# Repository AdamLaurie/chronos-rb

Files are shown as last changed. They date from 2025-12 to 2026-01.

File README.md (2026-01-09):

# ⚛️ CHRONOS-Rb

**C**ompact **H**igh-precision **R**ubidium **O**scillator **N**etwork **O**perating **S**ystem

A Stratum-1 NTP/PTP time server for Raspberry Pi Pico 2-W, disciplined by an FE-5680A rubidium atomic frequency standard.





## 🎯 Features

- **Stratum-1 NTP Server** - Direct atomic reference, no upstream servers needed
- **IEEE 1588 PTP Support** - Sub-microsecond precision time protocol
- **Rubidium Disciplined** - 10⁻¹¹ frequency stability from FE-5680A
- **WiFi Connected** - Serves time over 802.11 b/g/n
- **Web Interface** - Real-time status and configuration
- **JSON API** - Integration with monitoring systems
- **OTA Updates** - Encrypted firmware updates over WiFi with automatic rollback
- **PIO Precision** - Hardware-timed capture for <1µs accuracy
- **Automatic Holdover** - Maintains accuracy during reference loss
- **Interval Pulse Outputs** - 0.5s, 1s, 6s, 30s, 60s timing signals
- **AC Mains Frequency Monitor** - Grid frequency tracking with 48-hour history

## 📊 Specifications

| Parameter | Value |
|---|---|
| NTP Stratum | 1 (when locked) |
| Time Accuracy | < 1 µs to UTC |
| Frequency Stability | < 5×10⁻¹¹ (1 day) |
| PPS Jitter | < 100 ns |
| Warmup Time | 3-5 minutes |
| Power Consumption | ~35W during warmup, ~12W running |

## 🔧 Hardware Requirements

### Main Components

1. **Raspberry Pi Pico 2-W** - RP2350 with WiFi
2. **FE-5680A Rubidium Oscillator** - 10MHz output (DB-9 version)
3. **GPS Module** - u-blox NEO-6M or similar with 1PPS output (~$10-15)
4. **15V 3A Power Supply** - For rubidium physics package
5. **LT1016 or MAX999 Comparator** - 10MHz sine-to-square conversion
6. **Signal Conditioning Components** - See BOM in documentation

### Block Diagram

```
┌─────────────────┐     ┌──────────────────┐     ┌─────────────────┐
│   FE-5680A      │     │ Signal           │     │ Raspberry Pi    │
│   Rubidium      │────▶│ Conditioning     │────▶│ Pico 2-W        │
│   Oscillator    │     │ Circuit          │     │                 │
└─────────────────┘     └──────────────────┘     └────────┬────────┘
       │                        ▲                         │
       │ 10MHz Sine             │ 1PPS + NMEA             │ WiFi
       │ Lock Status            │                         ▼
       │                 ┌──────┴───────┐         ┌───────────────┐
       │                 │  GPS Module  │         │ NTP/PTP       │
       │                 │  (NEO-6M)    │         │ Clients       │
       │                 └──────────────┘         └───────────────┘
       │
       └─ Rb provides frequency stability (10⁻¹¹)
          GPS provides UTC alignment (±10ns)
```

## 📁 Project Structure

```
chronos-rb/
├── firmware/
│   ├── CMakeLists.txt          # Build configuration
│   ├── flash.sh                # Flashing helper script
│   ├── ota_key.txt             # AES encryption key (gitignored)
│   ├── deps/
│   │   └── pico_fota_bootloader/  # A/B partition bootloader
│   ├── include/
│   │   ├── chronos_rb.h        # Main header with configs
│   │   └── ota_update.h        # OTA update API
│   └── src/
│       ├── main.c              # Entry point
│       ├── pps_capture.c       # 1PPS timing capture
│       ├── pps_capture.pio     # PIO program for PPS
│       ├── freq_counter.c      # 10MHz measurement
│       ├── freq_counter.pio    # PIO program for freq
│       ├── rubidium_sync.c     # Rb sync state machine
│       ├── time_discipline.c   # PI controller
│       ├── ntp_server.c        # NTPv4 implementation
│       ├── ptp_server.c        # IEEE 1588 PTP
│       ├── wifi_manager.c      # WiFi handling
│       ├── web_interface.c     # HTTP status page + OTA
│       └── ota_update.c        # OTA firmware updates
├── hardware/
│   └── schematics/             # KiCad files (future)
└── docs/
    └── CHRONOS-Rb_Hardware_Guide.docx
```

## 🚀 Quick Start

### 1. Configure WiFi

Edit `firmware/include/chronos_rb.h`:

```c
#define WIFI_SSID_DEFAULT    "YourNetwork"
#define WIFI_PASS_DEFAULT    "YourPassword"
#define WIFI_COUNTRY         "US"
```

### 2. Build Firmware

```bash
cd firmware
mkdir build && cd build
cmake -DPICO_SDK_PATH=/path/to/pico-sdk ..
make -j4
```

**Build outputs:**
| File | Purpose |
|---|---|
| `pico_fota_bootloader.uf2` | A/B partition bootloader (flash first) |
| `chronos_rb.uf2` | Application firmware |
| `chronos_rb_fota_image_encrypted.bin` | Encrypted image for OTA updates |

### 3. Flash to Pico (First Time)

For new devices, flash the bootloader first, then the application:

**Option A: Using make targets**
```bash
# Flash bootloader, wait for reboot, then flash application
make flash-initial
```

**Option B: Manual BOOTSEL flashing**
```bash
# Step 1: Hold BOOTSEL, connect USB, copy bootloader
cp deps/pico_fota_bootloader/pico_fota_bootloader.uf2 /media/$USER/RP2350/

# Step 2: Hold BOOTSEL again, copy application
cp chronos_rb.uf2 /media/$USER/RP2350/
```

**Subsequent updates** can use OTA (see below) or:
```bash
make flash-app
```

### 4. Wire Hardware

See the Hardware Guide document for complete schematics. Key connections:

| Pico GPIO | Signal | Source |
|---|---|---|
| GP0 | GPS TX (UART0 TX) | To GPS module RX |
| GP1 | GPS RX (UART0 RX) | From GPS module TX |
| GP2 | 1PPS Input | From GPS module PPS |
| GP20 | 10MHz Input | FE-5680A via comparator |
| GP4/GP5 | I2C0 (optional) | For OLED display |
| GP6-9 | Status LEDs | With 330Ω resistors |
| GP22 | Lock Status | FE-5680A pin 3 via NPN level shifter |
| GP14 | 0.5s Pulse | Interval output |
| GP15 | 1s Pulse | Interval output |
| GP16 | 6s Pulse | Interval output |
| GP17 | 30s Pulse | Interval output |
| GP18 | 60s Pulse | Interval output |
| GP19 | AC Zero Cross | Zero crossing detector (optional) |

### 5. Power Up

1. Connect 15V to FE-5680A
2. Wait 3-5 minutes for rubidium lock
3. Green LED indicates sync achieved
4. Access web UI at `http://<ip-address>/`

## 📡 Using the Time Server

### NTP Client (Linux)

```bash
# Test connection
ntpdate -q 192.168.1.100

# Configure as time source
sudo nano /etc/systemd/timesyncd.conf
# Add: NTP=192.168.1.100
sudo systemctl restart systemd-timesyncd
```

### NTP Client (Windows)

```powershell
w32tm /config /manualpeerlist:192.168.1.100 /syncfromflags:manual /update
w32tm /resync
```

### Web Interface

Navigate to `http://<device-ip>/` for real-time status:

- Sync state (INIT → FREQ_CAL → COARSE → FINE → LOCKED)
- Time offset (nanoseconds)
- Frequency correction (ppb)
- NTP request count
- PTP sync statistics

### JSON API

```bash
curl http://192.168.1.100/api/status
```

```json
{
  "sync_state": 4,
  "rb_locked": true,
  "time_valid": true,
  "offset_ns": 127,
  "freq_offset_ppb": 0.023,
  "pps_count": 3847,
  "ntp_requests": 1542
}
```

## 📦 OTA Firmware Updates

CHRONOS-Rb supports encrypted over-the-air updates with automatic rollback protection.

### How It Works

- **A/B Partitioning**: Two firmware slots allow safe updates without bricking
- **AES-128 Encryption**: Firmware images are encrypted with a device-specific key
- **SHA-256 Validation**: Images are verified before applying
- **Automatic Rollback**: If the new firmware fails to boot 3 times, the previous version is restored
- **Boot Confirmation**: Firmware must run successfully for 60 seconds to be marked as good

### Web Interface Update

1. Navigate to `http://<device-ip>/ota`
2. Click "Choose File" and select `chronos_rb_fota_image_encrypted.bin`
3. Click "Upload Firmware" and wait for upload + validation
4. Click "Apply & Reboot" to install the update

### API Update

```bash
# Get OTA status
curl http://192.168.1.100/api/ota/status

# Upload firmware (chunked)
FILE="chronos_rb_fota_image_encrypted.bin"
SIZE=$(stat -c%s "$FILE")

# Begin upload
curl -X POST -H "X-OTA-Size: $SIZE" http://192.168.1.100/api/ota/begin

# Upload in chunks (1KB each)
split -b 1024 "$FILE" /tmp/chunk_
for chunk in /tmp/chunk_*; do
    curl -X POST --data-binary @"$chunk" \
         -H "Content-Type: application/octet-stream" \
         http://192.168.1.100/api/ota/chunk
done

# Finalize and validate
curl -X POST http://192.168.1.100/api/ota/finish

# Apply update (device will reboot)
curl -X POST http://192.168.1.100/api/ota/apply
```

### Encryption Key

The first build generates a random AES-128 key in `firmware/ota_key.txt`. This file is gitignored to keep it secret.

**Important:**
- Keep `ota_key.txt` backed up - you need it to create valid update images
- All firmware builds must use the same key to be accepted by the device
- If you lose the key, you must reflash via BOOTSEL

### Recovery

If an update fails and automatic rollback doesn't work:

1. Hold BOOTSEL button while connecting USB
2. Copy `pico_fota_bootloader.uf2` to the drive
3. Wait for reboot, hold BOOTSEL again
4. Copy `chronos_rb.uf2` to the drive

## 🔬 How It Works

### Time Discipline Loop

```
    ┌─────────────────────────────────────────────────┐
    │                                                 │
    ▼                                                 │
┌───────┐    ┌──────────┐    ┌────────────┐    ┌─────┴─────┐
│ 1PPS  │───▶│ Capture  │───▶│ Calculate  │───▶│    PI     │
│ Input │    │ (PIO)    │    │  Offset    │    │ Controller│
└───────┘    └──────────┘    └────────────┘    └───────────┘
                                                     │
                                                     ▼
┌───────────┐    ┌──────────┐    ┌────────────┐    ┌─────────┐
│ Timestamp │◀───│ Apply    │◀───│ Frequency  │◀───│Correction│
│ Output    │    │ Correction│   │  Adjust    │    │  (ppb)  │
└───────────┘    └──────────┘    └────────────┘    └─────────┘
```

### Sync State Machine

```
INIT ──▶ FREQ_CAL ──▶ COARSE ──▶ FINE ──▶ LOCKED
  │          │           │          │         │
  └──────────┴───────────┴──────────┴─────────┘
                         │
                    (on error)
                         ▼
                     HOLDOVER ──▶ ERROR
```

## 📐 Signal Conditioning

### 10MHz Sine to Square Converter

The FE-5680A outputs a ~860mVpp sine wave at ~0.7V DC. An LT1016 high-speed comparator converts this to 3.3V LVCMOS for the Pico:

```
           +5V         +5V
            │           │
           R2          ┌┴┐
          (6.8k)       │C1│ 0.1µF
            │          └┬┘
FE-5680A    │           │
Pin 7 ─────R1────┬─────Pin 1 (V+)
(10MHz)   (100Ω) │
                 │    ┌────────────┐
            Pin 2├────┤            ├─Pin 8──R6───LED──GND
            (+IN)│    │   LT1016   │       (500Ω) (purple)
                 │    │            │
            Pin 3├────┤            ├─Pin 7──R4───┬───► GP20
            (-IN)│    └────────────┘       (100Ω)│    (~3V)
                 │     │   │   │              R5
                R3    Pin4 Pin5 Pin6         (220Ω)
               (1k)    │   │   │              │
                │      └───┴───┴──────────────┴───GND
               GND

Threshold: ~0.64V from R2/R3 divider
Level shift: 5V→3V via R4/R5 divider
LED: On Q̅ (pin 8), lights when output LOW (inverted indicator)
```

**Components:**
- R1: 100Ω (input series resistor)
- R2: 6.8kΩ (threshold divider, top)
- R3: 1kΩ (threshold divider, bottom) → ~0.64V at -IN
- R4: 100Ω (level shifter, top)
- R5: 220Ω (level shifter, bottom) → ~3V output
- R6: 500Ω (LED current limit)
- C1: 0.1µF (bypass capacitor)
- U1: LT1016 (5V supply, 10ns comparator)
- 1× Purple LED (10MHz signal indicator, inverted)

**Notes:**
- No hysteresis feedback needed for 860mVpp signal
- LED on Q̅ (pin 8) to reduce loading on Q (pin 7)
- Lower value level shifter resistors prevent RC filtering at 10MHz

### GPS Module (Required)

A GPS module provides two critical functions:
1. **1PPS signal** - UTC-aligned pulse marking exact second boundaries (±10ns)
2. **Time-of-day** - NMEA sentences with current UTC time via UART

The firmware counts 10MHz cycles from the rubidium oscillator and verifies against GPS 1PPS to ensure exactly 10,000,000 cycles per second. This provides rubidium-level frequency stability with GPS-level UTC alignment.

#### Recommended Module: u-blox NEO-6M

Widely available as breakout boards (GY-GPS6MV2, GY-NEO6MV2):
- **Price:** ~$10-15
- **1PPS accuracy:** ±10ns to UTC
- **Interface:** UART (9600 baud default) + 1PPS output
- **Voltage:** 3.3-5V (check your specific board)

**Alternative:** BN-220 (~$15-20) - smaller form factor, same chipset

#### Wiring

```
GPS Module                              Pico
───────────                             ────
VCC ────────────────────────────────── 3.3V (or 5V if module requires)
GND ────────────────────────────────── GND
TX  ────────────────────────────────── GP1 (UART0 RX)
RX  ────────────────────────────────── GP0 (UART0 TX)
PPS ────────────────────────────────── GP2 (1PPS input)
```

**Note:** Most 3.3V GPS modules can connect directly. For 5V modules, add level shifting on PPS:

```
GPS 1PPS ──── R4 ────┬──── To Pico GP2
(5V)        (2.2k)   │
                     R5
                    (3.3k)
                     │
                    GND

Divider: 5V × 3.3k/(2.2k+3.3k) ≈ 3.0V
```

### Lock Status Level Shifter

The FE-5680A lock output (Pin 3) is 4.8V when unlocked, 0.8V when locked. An NPN transistor inverts and level-shifts this to 3.3V logic:

```
                      +3.3V
                        │
FE-5680A               R8 (1k)              +3.3V
Pin 3 ─── R6 ───┬───── B     C ─────┬─────── GP22 (HIGH = locked)
(Lock)   (22k)  │      ┌─────┐      │
                │      │2N3904│      ├─ R9 ─── GREEN LED ─── GND
           R7 ──┴─ GND │  Q1  │      │  (330Ω)   (locked)
          (10k)        └──┬──┘       │
                          E          └─ R10 ── YELLOW LED ── +3.3V
                          │             (330Ω)  (unlocked)
                         GND

Operation:
- Unlocked (4.8V): Q1 ON  → collector LOW  → YELLOW on,  GREEN off
- Locked (0.8V):   Q1 OFF → collector HIGH → YELLOW off, GREEN on
```

**Components:**
- 1× 2N3904 NPN transistor
- R6: 22kΩ (base input)
- R7: 10kΩ (base to GND)
- R8: 1kΩ (collector pull-up to 3.3V)
- R9: 330Ω (green LED current limit)
- R10: 330Ω (yellow LED current limit)
- 1× Green LED (indicates locked)
- 1× Yellow LED (indicates unlocked/warmup)

### AC Mains Frequency Monitor (Optional)

CHRONOS-Rb can monitor local AC grid frequency using off-the-shelf components. Grid frequency is tightly regulated and varies with load, providing an interesting indicator of grid stability.

#### Components

1. **AC Transformer**: [Carel TRA12UN100](https://cpc.farnell.com/carel/tra12un100/transformer-240vac-12vac/dp/MC01881)
   - 240VAC to 12VAC isolation transformer
   - 3VA rating (300mA max)
   - **Important**: Safe for very low load designs - output voltage stays at 13.8V (no load) to 10V (full load), unlike doorbell transformers that can spike to dangerous voltages under light load

2. **Zero Crossing Detector**: [Lectrobox AC Zero Crossing Detector](https://www.lectrobox.com/projects/zero-crossing-detector/)
   - 12VAC input via 5.5mm barrel jack
   - 3.3V output (0V/3.3V square wave indicating AC polarity)
   - SMA output connector
   - Built-in 100Hz RC filter for glitch resistance
   - Originally designed for grid frequency/phase measurement

#### Wiring

```
AC Mains ──► Transformer ──► Zero Crossing ──► Pico
  240V        TRA12UN100      Detector         GP19
               12VAC        (5.5mm jack)     (via SMA)
```

| Connection | Signal |
|---|---|
| Transformer primary | 240VAC mains (with appropriate fusing/isolation) |
| Transformer secondary | 12VAC to zero crossing detector barrel jack |
| Zero crossing SMA | 3.3V square wave to GP19 |

#### Features

- **Real-time frequency display**: Current grid frequency with 3 decimal precision
- **Hierarchical averaging**: Second → minute → hour averaging for noise reduction
- **48-hour history**: Stores 60 minute samples + 48 hour samples (~432 bytes)
- **Graph page**: Visual display at `/acfreq` showing minute and hour trends
- **API endpoint**: `/api/ac_history` returns JSON with `minutes[]` and `hours[]` arrays

#### Safety Notes

⚠️ **CAUTION**: AC mains voltage is dangerous. The transformer provides galvanic isolation between mains and low-voltage circuits.

- Use appropriate fusing on the primary side
- Ensure transformer is rated for your local mains voltage (230/240V or 110/120V)
- The TRA12UN100 is specifically designed for low-power monitoring applications
- Never connect the Pico directly to mains voltage

## ⏱️ Interval Pulse Outputs

CHRONOS-Rb provides five precision timing outputs synchronized to the rubidium 1PPS reference:

| GPIO | Interval | Use Case |
|---|---|---|
| GP14 | 0.5 second | High-rate timing, servo synchronization |
| GP15 | 1 second | PPS distribution, general timing |
| GP16 | 6 second | GPS-compatible timing intervals |
| GP17 | 30 second | Calibration triggers |
| GP18 | 60 second | Minute markers, event logging |

**Specifications:**
- Output level: 3.3V LVCMOS (active high)
- Pulse width: 10ms
- Timing accuracy: Phase-locked to atomic 1PPS reference
- Drive capability: 12mA (use buffer IC for cables/higher loads)

## 🐛 Troubleshooting

| Issue | Cause | Solution |
|---|---|---|
| No lock after 10 min | Power issue | Check +15V supply (needs 2A) |
| Erratic 1PPS | Bad connection | Check signal conditioning |
| WiFi fails | Wrong region | Set correct WIFI_COUNTRY |
| High offset | Comparator issue | Verify 10MHz square wave |
| NTP timeout | Firewall | Open UDP port 123 |

## 📜 License

MIT License - See LICENSE file for details.

## 🙏 Acknowledgments

- Raspberry Pi Foundation for the Pico SDK
- The time-nuts community for rubidium oscillator knowledge
- NTP and PTP specification authors

---

**CHRONOS-Rb** - *Because every nanosecond counts* ⚛️⏱️

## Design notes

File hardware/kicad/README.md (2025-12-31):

# CHRONOS-Rb KiCad Project

This directory contains the KiCad hardware design files for the CHRONOS-Rb Rubidium Time Server signal conditioning and interface board.

## Requirements

- **KiCad Version:** 7.0 or later (8.0 recommended)
- **Target Platform:** Raspberry Pi Pico 2-W (RP2350 with WiFi)
- **Reference Clock:** FE-5680A Rubidium Frequency Standard

## Project Structure

```
kicad/
├── chronos_rb.kicad_pro     # Main project file
├── chronos_rb.kicad_sch     # Top-level schematic (block diagram)
├── power_supply.kicad_sch   # Power supply: 15V/5V/3.3V rails
├── signal_conditioning.kicad_sch  # 10MHz comparator & 1PPS level shifter
├── pico_interface.kicad_sch # Raspberry Pi Pico 2-W connections
├── connectors.kicad_sch     # FE-5680A & external connectors
├── sym-lib-table            # Symbol library references
├── fp-lib-table             # Footprint library references
├── symbols/
│   └── chronos_rb.kicad_sym # Custom symbol library
├── footprints/
│   └── chronos_rb.pretty/   # Custom footprint library
├── 3dmodels/                # 3D models for components
└── gerbers/                 # Manufacturing output files
```

## Design Rules (JLCPCB Compatible)

The project is configured with design rules suitable for JLCPCB manufacturing:

| Parameter | Value |
|---|---|
| Minimum trace width | 6 mil (0.1524 mm) |
| Minimum trace spacing | 6 mil (0.1524 mm) |
| Minimum via diameter | 0.5 mm |
| Minimum via drill | 0.3 mm |
| Minimum hole size | 0.3 mm |
| Copper to edge clearance | 0.3 mm |

## Schematic Hierarchy

1. **Top Level** (`chronos_rb.kicad_sch`)
   - Block diagram overview
   - Power distribution reference
   - Signal flow documentation

2. **Power Supply** (`power_supply.kicad_sch`)
   - 15V input for FE-5680A (2-3A during warmup)
   - 5V regulated rail for logic
   - 3.3V LDO for Pico and signal conditioning

3. **Signal Conditioning** (`signal_conditioning.kicad_sch`)
   - 10MHz sine-to-square converter (LT1016/MAX999)
   - 1PPS 5V to 3.3V level shifter
   - Lock status input conditioning
   - ESD protection

4. **Pico Interface** (`pico_interface.kicad_sch`)
   - Pico 2-W module connections
   - Decoupling and power filtering
   - Status LED drivers
   - Interval output buffers
   - Debug/programming headers

5. **Connectors** (`connectors.kicad_sch`)
   - FE-5680A DB-9 interface
   - DC power input
   - Optional external timing outputs (BNC/SMA)

## Usage

1. Open `chronos_rb.kicad_pro` in KiCad 7.0+
2. The top-level schematic shows the system block diagram
3. Double-click hierarchical sheets to navigate to sub-schematics
4. Custom symbols are in the `chronos_rb` library
5. Export gerbers to the `gerbers/` directory for manufacturing

## Critical Signals

| Signal | Description | Level |
|---|---|---|
| PPS_IN | 1PPS from divider or external GPS | 3.3V (level shifted if needed) |
| CLK_10MHZ | 10MHz reference | 3.3V LVCMOS (from 1Vpp sine) |
| RB_LOCK | Rubidium lock status | Active low, 3.3V |

## GPIO Mapping (Pico 2-W)

| GPIO | Function |
|---|---|
| GP2 | PPS input (PIO capture) |
| GP3 | 10MHz input (frequency counter) |
| GP4 | Rubidium lock status |
| GP6-9 | Status LEDs |
| GP14-18 | Interval pulse outputs |

## License

Open Source Hardware - See main project LICENSE file.

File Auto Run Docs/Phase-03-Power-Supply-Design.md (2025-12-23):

# Phase 03: Power Supply Design

This phase creates the complete power supply subsystem for CHRONOS-Rb using **mains AC input** (100-240V AC, 50/60Hz). The FE-5680A rubidium oscillator requires 15V at 2-3A during warmup (dropping to ~1A steady-state), while the signal conditioning and Pico require regulated 5V and 3.3V rails. The power supply includes a zero-crossing detector circuit to monitor local AC mains frequency via a GPIO input.

**SAFETY WARNING**: This design involves mains AC voltage which can cause serious injury or death. All mains-connected circuitry must be properly isolated, fused, and enclosed. Follow all local electrical codes and regulations.

## Specifications

- **Input**: 100-240V AC, 50/60Hz (universal mains input)
- **Outputs**: +15V @ 3A (FE-5680A), +5V @ 1A (logic), +3.3V @ 500mA (digital), +3.3V @ 100mA (analog)
- **Isolation**: Reinforced isolation between mains and low-voltage sections
- **Features**: Mains frequency monitoring via GPIO (zero-crossing detector)

## Power Conversion Block Diagram

```
┌─────────────────────────────────────────────────────────────────────────────┐
│                              MAINS SIDE (HAZARDOUS)                         │
│  ┌─────────┐    ┌─────────┐    ┌─────────┐    ┌─────────┐    ┌──────────┐  │
│  │ IEC C14 │───>│  Fuse   │───>│   EMI   │───>│ Bridge  │───>│  Bulk    │  │
│  │  Inlet  │    │   2A    │    │ Filter  │    │Rectifier│    │  Cap     │  │
│  │100-240V │    │slow-blow│    │  + MOV  │    │ GBU806  │    │470uF/400V│  │
│  └─────────┘    └─────────┘    └─────────┘    └─────────┘    └────┬─────┘  │
│                                     │                              │        │
│                                     │                         140-340V DC   │
│                                     │                              │        │
│                              ┌──────┴──────┐               ┌───────┴──────┐ │
│                              │Zero-Crossing│               │   Isolated   │ │
│                              │  Detector   │               │   Flyback    │ │
│                              │   H11AA1    │               │  DC-DC Conv  │ │
│                              └──────┬──────┘               └───────┬──────┘ │
│                                     │                              │        │
├─────────────────────────────────────│──────────────ISOLATION───────│────────┤
│                              LOW VOLTAGE SIDE                      │        │
│                                     │                              │        │
│                              ┌──────┴──────┐               ┌───────┴──────┐ │
│                              │   GP19      │               │    +15V      │ │
│                              │  (Pico)     │               │   @ 3A       │ │
│                              │AC_ZERO_CROSS│               │  (FE-5680A)  │ │
│                              └─────────────┘               └───────┬──────┘ │
│                                                                    │        │
│                                                            ┌───────┴──────┐ │
│                                                            │   LM2596     │ │
│                                                            │  Buck Conv   │ │
│                                                            └───────┬──────┘ │
│                                                                    │        │
│                                                            ┌───────┴──────┐ │
│                                                            │     +5V      │ │
│                                                            │    @ 1A      │ │
│                                                            └───────┬──────┘ │
│                                                                    │        │
│                                                     ┌──────────────┼───────┐│
│                                                     │              │       ││
│                                              ┌──────┴─────┐ ┌──────┴─────┐ ││
│                                              │ AMS1117    │ │  LP5907    │ ││
│                                              │   LDO      │ │ Low-noise  │ ││
│                                              └──────┬─────┘ └──────┬─────┘ ││
│                                                     │              │       ││
│                                              ┌──────┴─────┐ ┌──────┴─────┐ ││
│                                              │+3.3V Digital│ │+3.3V Analog│ ││
│                                              │  @ 500mA   │ │  @ 100mA   │ ││
│                                              └────────────┘ └────────────┘ ││
└─────────────────────────────────────────────────────────────────────────────┘
```

## Zero-Crossing Detector Circuit

The H11AA1 is an AC-input optocoupler with two back-to-back LEDs, providing isolation while detecting both positive and negative zero crossings of the AC waveform.

```
        MAINS SIDE                    │            LOW VOLTAGE SIDE
        (ISOLATED)                    │
                                      │
    AC Live (L) ───┬──────────────────│
                   │                  │
                  ┌┴┐                 │
                  │ │ R1              │
                  │ │ 47k 1/2W        │
                  └┬┘                 │              +3.3V
                   │                  │                │
                  ┌┴┐                 │               ┌┴┐
                  │ │ R2              │               │ │ R3
                  │ │ 47k 1/2W        │               │ │ 10k
                  └┬┘                 │               └┬┘
                   │    ┌─────────┐   │                │
                   ├────┤1  H11AA1├───│────────────────┼──────> To GP19
                   │    │   opto  │   │                │        (AC_ZERO_CROSS)
                   │  ┌─┤2       4├─┬─│────────────────┘
                   │  │ └─────────┘ │ │
                   │  │             │ │
    AC Neutral (N)─┴──┴─────────────┴─│─────> GND (isolated from mains)
                                      │
                                      │
                              ISOLATION BARRIER
                              (3kV reinforced)
```

**Component Details:**
- **R1, R2**: 47kΩ 1/2W resistors in series (94kΩ total) - limits LED current to ~2.5mA at 240VAC peak
- **H11AA1**: AC-input optocoupler with back-to-back LEDs, 5.3kV isolation rating
- **R3**: 10kΩ pull-up to 3.3V - output is LOW during zero-crossing, HIGH otherwise

**Output Signal:**
- Produces a pulse at each zero crossing (both positive and negative)
- Pulse frequency = 2× mains frequency (100Hz for 50Hz mains, 120Hz for 60Hz mains)
- Firmware measures time between pulses to calculate mains frequency
- Connected to **GP19** (GPIO_AC_ZERO_CROSS) on Pico 2-W

## Tasks

### AC Input Section (Mains-Isolated)
- [ ] In `power_supply.kicad_sch`, create the AC mains input section with IEC C14 inlet connector (fused, with EMI filter)
- [ ] Add mains fuse holder with 2A slow-blow fuse (5x20mm) on the live conductor
- [ ] Add MOV (Metal Oxide Varistor) across L-N for transient surge suppression (275V AC rating, e.g., EPCOS B72210S0271K101)
- [ ] Add X2-class capacitor (100nF 275VAC) across L-N for differential mode EMI filtering
- [ ] Add Y1-class capacitors (2x 2.2nF 250VAC) from L and N to PE (protective earth) for common mode filtering
- [ ] Add common mode choke (10mH, 3A rated) for EMI suppression
- [ ] Create a clearly marked **HAZARDOUS VOLTAGE AREA** on schematic with safety notes

### Bridge Rectifier and Bulk Capacitor
- [ ] Add full-bridge rectifier (GBU806 or KBU810, 600V/8A rating) with proper heatsinking consideration
- [ ] Add bulk capacitor: 470uF/400V electrolytic for energy storage (calculate ripple current rating)
- [ ] Add bleeder resistor (470k, 1W) across bulk capacitor for discharge when unplugged
- [ ] Calculate DC bus voltage: ~140V DC (100V AC) to ~340V DC (240V AC)

### Isolated DC-DC Converter (15V Output)
- [ ] Use isolated flyback or forward converter topology for 15V @ 3A output (e.g., based on TNY290PG or similar offline switcher)
- [ ] Alternatively, use a pre-built AC-DC module (Mean Well IRM-45-15 or similar) for safety and certification
- [ ] Add opto-isolator (PC817 or 4N35) for feedback loop isolation
- [ ] Add isolation transformer with proper creepage/clearance distances (reinforced isolation, 3kV minimum)
- [ ] Add output capacitors: 1000uF/25V electrolytic + 100nF ceramic for the 15V rail
- [ ] Create the 15V filtered output for FE-5680A with additional LC filter: 10uH inductor, 100uF output capacitor

### Zero-Crossing Detector (Mains Frequency Monitor)
- [ ] Create isolated zero-crossing detector circuit using optocoupler (H11AA1 or similar AC-input opto)
- [ ] Add 100k current-limiting resistors (2x 47k in series for voltage rating) from mains L-N to opto LED
- [ ] Output: 3.3V-compatible pulse on each zero crossing (100/120 Hz for 50/60 Hz mains)
- [ ] Connect opto collector to GPIO with 10k pull-up to 3.3V
- [ ] Add net label: AC_ZERO_CROSS (connects to Pico GPIO for frequency measurement)
- [ ] Add schematic note: "Pulse output at 2x mains frequency for firmware frequency measurement"

### Secondary Regulators (5V and 3.3V Rails)
- [ ] Create the 5V switching regulator section from 15V input using LM2596-5.0 or TPS5430
- [ ] Add input capacitors (100uF/25V), output inductor (68uH), output capacitors (220uF + 100nF), Schottky diode (SS34)
- [ ] Add output voltage test point for the 5V rail with silk screen label "5V_TEST"
- [ ] Create the 3.3V LDO section using AMS1117-3.3 or AP2112K-3.3 from 5V input
- [ ] Add input capacitor (10uF), output capacitors (10uF + 100nF)
- [ ] Add a second 3.3V LDO specifically for analog circuits (comparator supply) using low-noise regulator LP5907-3.3
- [ ] Create power-on LED indicators: green LED with 1k resistor from 3.3V rail, amber LED with 2.2k resistor from 5V rail

### Protection and Monitoring
- [ ] Add current sense resistor (0.1 ohm, 1W) in the 15V path for monitoring warmup current
- [ ] Add power good output signal using voltage supervisor circuit (TL7705) monitoring 5V rail
- [ ] Add power rail decoupling network: 100uF bulk + 10uF + 100nF + 10nF for each rail
- [ ] Add TVS diode (SMBJ18A) on 15V output for secondary-side surge protection

### Documentation and Labels
- [ ] Create power sequencing note: "15V powers up first (from AC-DC), then 5V, then 3.3V (cascaded regulators)"
- [ ] Add net labels: +15V_RB, +5V, +3V3_DIGITAL, +3V3_ANALOG, GND, PWR_GOOD, AC_ZERO_CROSS
- [ ] Add power dissipation calculations as text notes
- [ ] Add safety markings: "DANGER: HIGH VOLTAGE", isolation boundary markers
- [ ] Add hierarchical labels for power outputs connecting to other sheets
- [ ] Document creepage/clearance requirements for mains isolation (minimum 6mm creepage for reinforced isolation)

### Firmware Integration
- [ ] Add GPIO_AC_ZERO_CROSS pin definition to chronos_rb.h (recommend GP19 or GP20)
- [ ] Create ac_freq_monitor.c/h module to measure mains frequency from zero-crossing pulses
- [ ] Add CLI command "acfreq" to display measured mains frequency
- [ ] Display AC frequency in status output and web interface

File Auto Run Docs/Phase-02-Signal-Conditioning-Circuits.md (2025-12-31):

# Phase 02: Signal Conditioning Circuits

This phase implements the critical signal conditioning circuits that convert the FE-5680A rubidium oscillator outputs into Pico-compatible logic levels. The 10MHz sine wave requires conversion to 3.3V LVCMOS using a high-speed comparator. Note: Most FE-5680A units (including the DB-9 version) do NOT have a native 1PPS output - it must be derived from the 10MHz using a divider circuit or sourced from an external GPS/GNSS receiver. If using an external 5V 1PPS source, level shifting with ESD protection is required.

## Tasks

- [ ] Create a custom KiCad symbol for the LT1016 high-speed comparator in `symbols/chronos_rb.kicad_sym` with all pins: +IN (pin 2), -IN (pin 3), V+ (pin 8), V- (pin 4), OUT (pin 7), GND (pin 1), LATCH (pin 5), Q_bar (pin 6)
- [ ] Create an alternative symbol for MAX999 comparator as a drop-in option with compatible pinout
- [ ] In `signal_conditioning.kicad_sch`, create the 10MHz comparator circuit section with LT1016, input AC coupling capacitor (100nF), bias resistor divider (10k/10k) to set DC operating point at V+/2
- [ ] Add 50-ohm input termination resistor for the 10MHz signal to match FE-5680A output impedance
- [ ] Add decoupling capacitors for the LT1016: 100nF ceramic on V+ to GND, 10uF tantalum on V+ to GND
- [ ] Add a hysteresis feedback network to the comparator (100k from output to +IN, optional 1M to threshold) to prevent oscillation on slow edges
- [ ] Add output series resistor (33 ohm) on comparator output to limit edge rate and reduce EMI
- [ ] Create the 1PPS level shifter section (for external 5V source) using resistive divider: 1.8k from 5V input, 3.3k to GND, achieving 3.08V output from 5V input
- [ ] Add BAT54S Schottky diode clamp from divider output to 3.3V rail and GND for overvoltage/ESD protection
- [ ] Add 100pF capacitor across the lower resistor of the divider to preserve fast PPS edges while filtering noise
- [ ] Create input protection on the 1PPS line: 100 ohm series resistor before the divider to limit surge current
- [ ] Add a buffer stage after the 1PPS divider using a 74LVC1G17 Schmitt trigger for clean digital edges (optional but recommended section)
- [ ] Create the RB_LOCK status input circuit: NPN transistor (2N3904) level shifter with 22k input resistor, 10k base-to-GND resistor, 10k collector pull-up to 3.3V. FE-5680A outputs 4.8V (unlocked) / 0.8V (locked), transistor inverts to GPIO HIGH=locked, LOW=unlocked
- [ ] Add net labels to all signal conditioning outputs: CLK_10MHZ_3V3, PPS_3V3, RB_LOCK_3V3
- [ ] Add test points (TP symbols) at critical nodes: 10MHz input, 10MHz output, 1PPS input (from divider/ext), 1PPS output, comparator threshold
- [ ] Create hierarchical labels for signals that connect to the Pico Interface sheet
- [ ] Add component annotations and values for all parts with designator prefixes: U for ICs, R for resistors, C for capacitors, D for diodes, TP for test points
- [ ] Add text notes on the schematic explaining signal levels: "Input: 1Vpp sine @ 10MHz" and "Output: 3.3V LVCMOS @ 10MHz, <1ns jitter"

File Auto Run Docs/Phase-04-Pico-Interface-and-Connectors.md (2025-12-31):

# Phase 04: Pico Interface and Connectors

This phase designs the Raspberry Pi Pico 2-W interface circuitry and all external connectors. The Pico serves as the main processor running the NTP/PTP server firmware, receiving timing signals from the signal conditioning stage. This phase also includes the FE-5680A connector interface, status LEDs, debug headers, and optional expansion connectors for external timing outputs.

## Tasks

- [ ] Create or import a Raspberry Pi Pico 2-W symbol in `symbols/chronos_rb.kicad_sym` showing all 40 pins with correct GPIO assignments per RP2350 datasheet
- [ ] In `pico_interface.kicad_sch`, place the Pico 2-W symbol with proper orientation (USB connector facing board edge)
- [ ] Create two 20-pin female header footprints for Pico mounting (2.54mm pitch, standard Pico socket arrangement)
- [ ] Connect power pins: VSYS to 5V rail, 3V3_EN to 3.3V (via 10k pullup), GND pins to ground plane
- [ ] Connect timing inputs from signal conditioning: GP2 to PPS_3V3, GP3 to CLK_10MHZ_3V3, GP4 to RB_LOCK_3V3
- [ ] Add 33 ohm series resistors on timing inputs for trace impedance matching and ESD protection
- [ ] Create status LED circuit section with 4 LEDs: green (GP6/SYNC), blue (GP7/NETWORK), yellow (GP8/ACTIVITY), red (GP9/ERROR)
- [ ] Add 470 ohm current limiting resistors for each LED (approximately 5mA per LED at 3.3V)
- [ ] Connect optional RB_ENABLE output on GP5 with 10k series resistor for FE-5680A control
- [ ] Create debug/diagnostic output section: GP10 (PPS_OUT), GP11 (SYNC_PULSE) with series resistors and test points
- [ ] Connect UART debug pins: GP0 (TX) and GP1 (RX) to a 3-pin debug header (TX, RX, GND)
- [ ] Create I2C header for optional OLED display: GP12 (SDA), GP13 (SCL), 3.3V, GND on a 4-pin connector
- [ ] Add I2C pull-up resistors (4.7k) on SDA and SCL lines
- [ ] Create interval pulse output section on GP14-GP18 with individual 100 ohm series resistors
- [ ] Add a 6-pin header for interval pulse outputs: 0.5s, 1s, 6s, 30s, 60s, and GND
- [ ] In `connectors.kicad_sch`, create the FE-5680A connector interface using a DB-9 female connector
- [ ] Map DB-9 pins per FE-5680A pinout: pin 1 (+15V), pin 2 (GND), pin 3 (LOCK), pin 4 (+5V), pin 5 (GND), pin 7 (10MHz)
- [ ] Note: 1PPS may need to be derived from 10MHz using a divider circuit (not all FE-5680A units have 1PPS output)
- [ ] Create a 2-pin screw terminal for +15V power input as alternative to barrel jack
- [ ] Add a USB-C or micro-USB breakout connector for Pico programming access
- [ ] Create an SMA or BNC connector footprint for external 10MHz reference output (active buffer from Pico output)
- [ ] Add an SMA connector for external 1PPS output with 50-ohm driver circuit using 74LVC2G17 buffer
- [ ] Create mounting hole symbols (M3) at board corners, connected to GND for shielding
- [ ] Add board edge connector for stacking or enclosure integration (2x10 pin header with power and key signals)
- [ ] Create net labels for all GPIO connections matching firmware definitions in chronos_rb.h
- [ ] Add hierarchical labels connecting all sheets together for power and signals

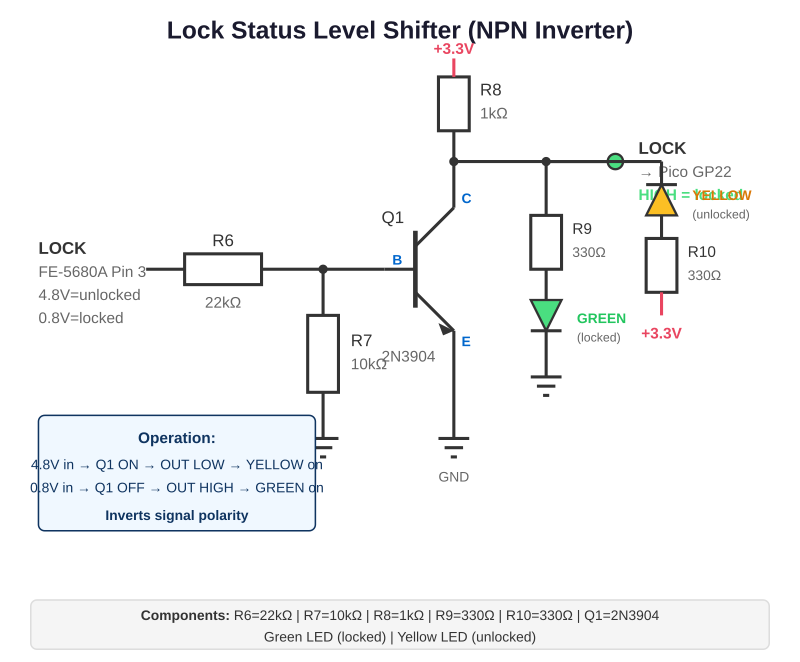
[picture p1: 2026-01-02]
hardware/lock_detector.png

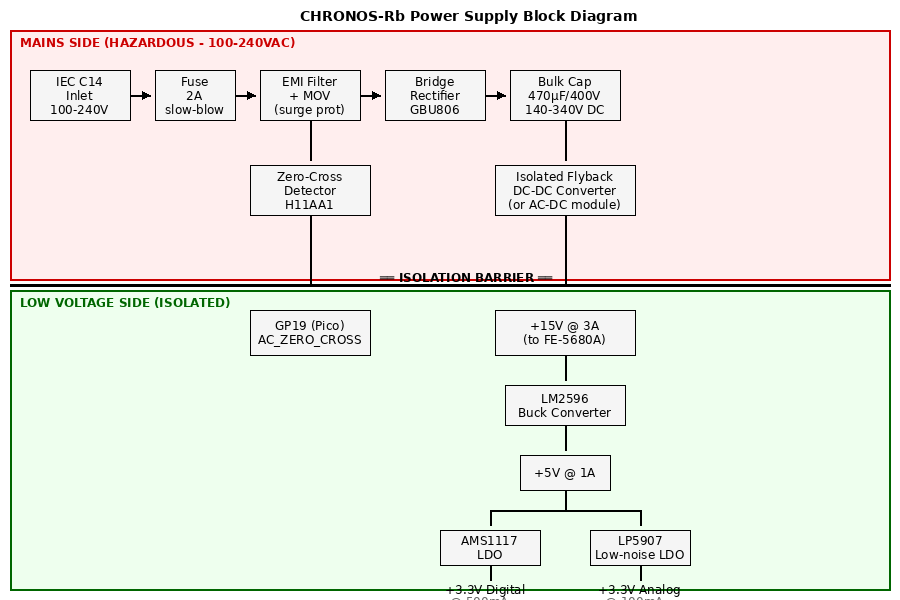
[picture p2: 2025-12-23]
hardware/power_supply.png

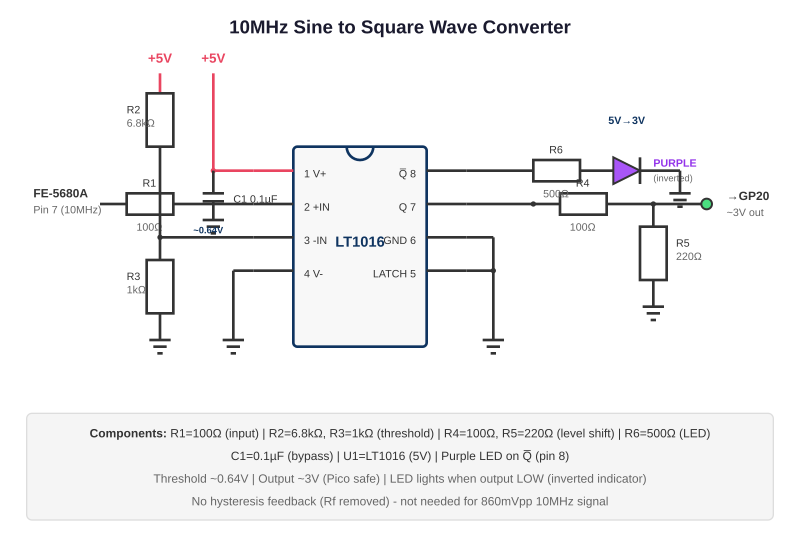
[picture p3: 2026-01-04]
hardware/10mhz_comparator.png

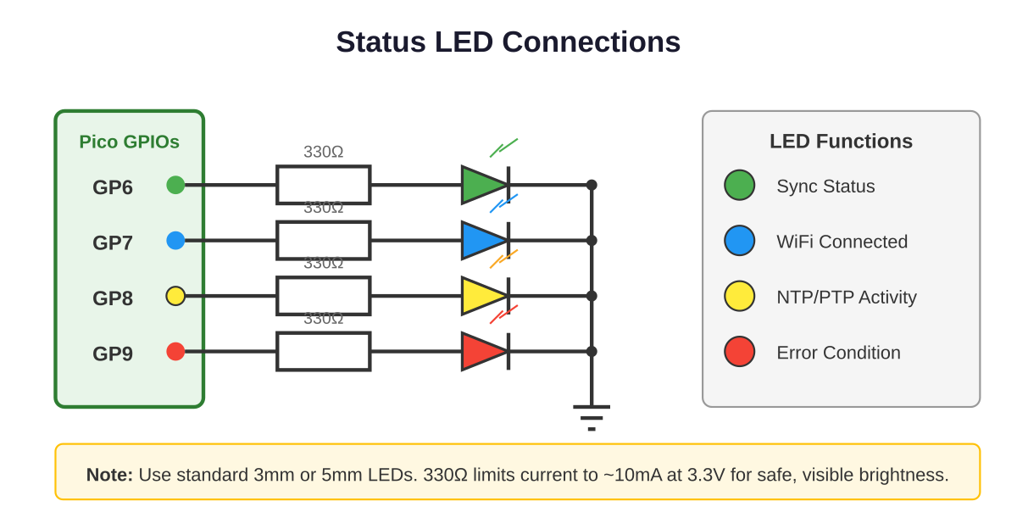
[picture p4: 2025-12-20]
hardware/led_circuit.png

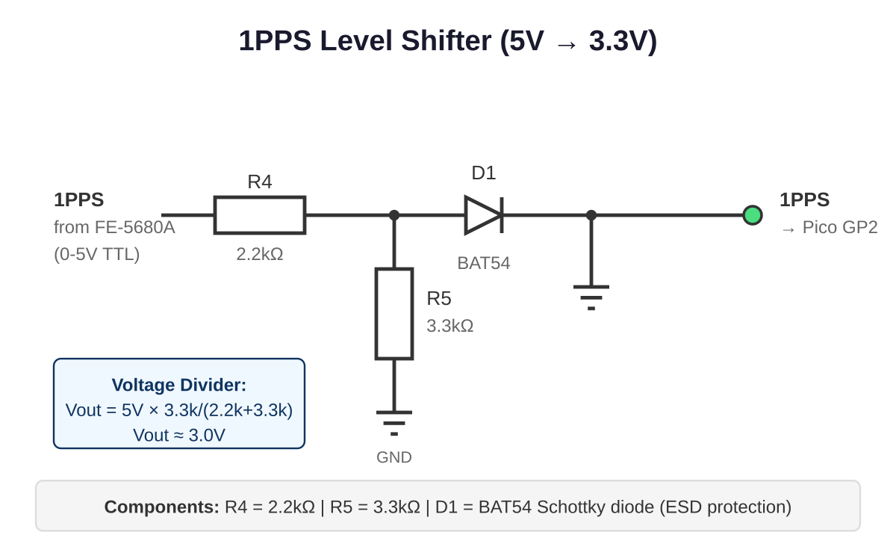
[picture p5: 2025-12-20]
hardware/1pps_levelshifter.png

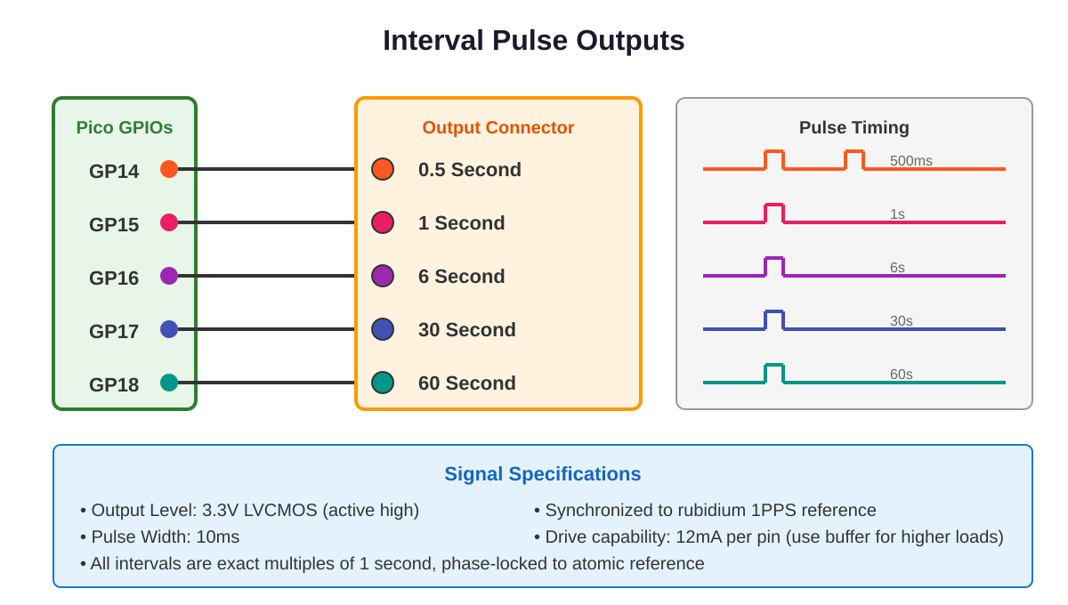
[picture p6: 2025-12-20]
hardware/interval_pulses.png

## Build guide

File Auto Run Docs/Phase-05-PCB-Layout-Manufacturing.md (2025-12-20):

# Phase 05: PCB Layout and Manufacturing Files

This phase transforms the completed schematics into a manufacturable PCB design. The layout requires careful attention to signal integrity for the high-speed 10MHz clock, proper grounding for noise immunity, thermal management for power components, and adherence to JLCPCB design rules for automated fabrication. The final deliverables include Gerber files, drill files, BOM, and pick-and-place data ready for ordering.

## Tasks

- [ ] Create the PCB file `chronos_rb.kicad_pcb` with board outline: 100mm x 80mm rectangle with 3mm corner radius, 4-layer stackup (Signal-GND-PWR-Signal)
- [ ] Define layer stackup in board settings: 0.035mm copper, 0.2mm prepreg, 1.0mm core, matching JLCPCB 4-layer standard
- [ ] Set design rules for JLCPCB capabilities: 0.15mm (6mil) min trace, 0.15mm min space, 0.3mm min drill, 0.45mm min via
- [ ] Add mounting holes at four corners (M3, 3.2mm diameter) with keepout zones
- [ ] Run "Update PCB from Schematic" to import all components with netlist
- [ ] Place power supply components in lower-left quadrant with input connector at board edge
- [ ] Place FE-5680A DB-9 connector at board edge near power input section
- [ ] Place Pico 2-W headers in central area with USB connector accessible at board edge
- [ ] Place signal conditioning components between FE-5680A connector and Pico, minimizing trace length
- [ ] Place status LEDs along one board edge for visibility
- [ ] Place debug and expansion headers along remaining board edges
- [ ] Create ground plane on layer 2 (inner) as solid copper pour connected to GND net
- [ ] Create power plane on layer 3 (inner) with split planes for +3.3V and +5V zones
- [ ] Route critical 10MHz signal with controlled impedance: 50-ohm microstrip, keep trace short and direct
- [ ] Route 1PPS signal with ground guard traces on either side for noise immunity
- [ ] Route power traces with appropriate width: 15V traces at 1mm (2A capacity), 5V at 0.5mm, 3.3V at 0.3mm
- [ ] Add via stitching around board perimeter for EMI containment (every 5mm)
- [ ] Add via stitching around high-speed signal areas connecting top and bottom ground
- [ ] Place decoupling capacitors as close as possible to IC power pins with direct via to ground plane
- [ ] Add thermal relief on power plane connections to allow hand soldering
- [ ] Create copper pour on top and bottom layers connected to GND, with appropriate clearances
- [ ] Add silk screen labels for all connectors, test points, and component designators
- [ ] Add silk screen text: "CHRONOS-Rb v1.0", website/project URL, and license text
- [ ] Add polarity markings near electrolytic capacitors and diodes
- [ ] Run Design Rule Check (DRC) and resolve all errors and warnings
- [ ] Run Electrical Rules Check (ERC) on schematic and resolve all issues
- [ ] Generate Gerber files in `gerbers/` subdirectory: F.Cu, B.Cu, In1.Cu, In2.Cu, F.SilkS, B.SilkS, F.Mask, B.Mask, Edge.Cuts
- [ ] Generate drill files (Excellon format) for PTH and NPTH holes
- [ ] Generate pick-and-place file (CPL) in CSV format with component XY coordinates and rotations
- [ ] Generate Bill of Materials (BOM) in CSV format with: designator, value, footprint, manufacturer, part number, quantity
- [ ] Create ZIP archive of Gerber files ready for JLCPCB upload: `chronos_rb_gerbers_v1.0.zip`
- [ ] Verify Gerber files using an online Gerber viewer (document the verification step in README)
- [ ] Update `hardware/kicad/README.md` with manufacturing instructions: layer count, board thickness, surface finish (HASL or ENIG), and recommended JLCPCB options

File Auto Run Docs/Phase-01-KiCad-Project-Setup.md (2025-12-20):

# Phase 01: KiCad Project Setup and Core Schematic Structure

This phase establishes the complete KiCad project infrastructure for CHRONOS-Rb and creates the hierarchical schematic structure with all sheet organization. By the end of this phase, you will have a fully configured KiCad project with organized schematic sheets, custom symbol library foundations, and a working top-level block diagram that can be opened and viewed in KiCad. This provides the essential framework upon which all subsequent hardware design will be built.

## Tasks

- [x] Create the KiCad project directory structure at `hardware/kicad/` with subdirectories: `symbols/`, `footprints/`, `3dmodels/`, and `gerbers/`
  - Created directory structure: `hardware/kicad/` with `symbols/`, `footprints/`, `3dmodels/`, and `gerbers/` subdirectories
- [x] Create the main KiCad project file `chronos_rb.kicad_pro` with project settings configured for 1-layer PCB, metric units, and design rules suitable for JLCPCB manufacturing (6mil trace/space minimum)
  - Created project file with JLCPCB-compatible design rules: 6mil (0.1524mm) minimum trace/space, 0.5mm via diameter, 0.3mm via drill. Configured net classes for Default and Power with appropriate track widths. Set gerber output path and project metadata.
- [x] Create the top-level schematic file `chronos_rb.kicad_sch` with project title block containing: "CHRONOS-Rb Rubidium Time Server", revision "1.0", date field, and author placeholder
  - Created A3-sized top-level schematic with complete title block: title "CHRONOS-Rb Rubidium Time Server", rev "1.0", date "2024-12-20", company "Open Source Hardware", and comments describing Stratum-1 NTP/PTP functionality.
- [x] Add hierarchical sheet symbols to the top-level schematic for: "Power Supply" (power_supply.kicad_sch), "Signal Conditioning" (signal_conditioning.kicad_sch), "Pico Interface" (pico_interface.kicad_sch), and "Connectors" (connectors.kicad_sch)
  - Added four hierarchical sheet symbols to top-level schematic, arranged horizontally with proper sheet references and page numbers (pages 2-5).
- [x] Create the Power Supply sub-schematic `power_supply.kicad_sch` with empty sheet and title block labeled "Power Supply - 15V/5V/3.3V Rails"
  - Created with title block, descriptive comments about input/output voltage rails, and placeholder text documenting planned contents (input protection, switching regulator, LDO, filtering).
- [x] Create the Signal Conditioning sub-schematic `signal_conditioning.kicad_sch` with empty sheet and title block labeled "Signal Conditioning - 10MHz Comparator & 1PPS Level Shifter"
  - Created with title block documenting LT1016/MAX999 comparator for 10MHz, resistive divider for 1PPS, and ESD protection requirements.
- [x] Create the Pico Interface sub-schematic `pico_interface.kicad_sch` with empty sheet and title block labeled "Raspberry Pi Pico 2-W Interface"
  - Created with title block documenting RP2350, PIO timing inputs (GP2, GP3), and status/interval outputs (GP6-9, GP14-18).
- [x] Create the Connectors sub-schematic `connectors.kicad_sch` with empty sheet and title block labeled "FE-5680A & External Connectors"
  - Created with title block documenting DB-9 interface pinout, power input, and optional BNC/SMA timing outputs.
- [x] Create the custom symbol library file `symbols/chronos_rb.kicad_sym` with library header and metadata
  - Created KiCad 8.0 format symbol library with placeholder symbol. Library ready for custom components like FE-5680A connector, Pico 2-W module, LT1016 comparator.
- [x] Create the custom footprint library file `footprints/chronos_rb.pretty/` directory (KiCad footprint library format)
  - Created empty footprint library directory in KiCad .pretty format. Ready for custom footprints.
- [x] Create a `fp-lib-table` file in the project directory that references the custom footprint library
  - Created fp-lib-table referencing chronos_rb.pretty using ${KIPRJMOD} variable for portability.
- [x] Create a `sym-lib-table` file in the project directory that references the custom symbol library
  - Created sym-lib-table referencing chronos_rb.kicad_sym using ${KIPRJMOD} variable for portability.
- [x] Add global power symbols (+15V, +5V, +3.3V, GND) and power flags to the top-level schematic as a power distribution reference
  - Added global labels for +15V, +5V, +3V3, and GND on the top-level schematic as power distribution reference points.
- [x] Create net labels on the top-level schematic for critical signals: PPS_IN, CLK_10MHZ, RB_LOCK, and the GPIO bus connections
  - Added net labels for PPS_IN, CLK_10MHZ, and RB_LOCK on top-level schematic. GPIO connections documented in text annotations.
- [x] Add text annotations to the top-level schematic documenting the signal flow: "FE-5680A → Signal Conditioning → Pico 2-W → Network Output"
  - Added signal flow annotation and detailed text describing power rails and critical signals with their voltage levels and conditioning requirements.
- [x] Create a `README.md` file in `hardware/kicad/` documenting the project structure, required KiCad version (7.0+), and basic usage instructions
  - Created comprehensive README with project structure, design rules table, schematic hierarchy description, critical signals table, GPIO mapping, and usage instructions.

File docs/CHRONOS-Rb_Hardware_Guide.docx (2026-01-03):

# CHRONOS-Rb

Compact High-precision Rubidium Oscillator Network Operating System

Hardware Design & Assembly Guide

Raspberry Pi Pico 2-W NTP/PTP Server

Synchronized to FE-5680A Rubidium Frequency Standard

Version 1.0

Open Source Hardware Project

# 1. Project Overview

CHRONOS-Rb is a high-precision NTP/PTP time server based on the Raspberry Pi Pico 2-W microcontroller, disciplined by an FE-5680A rubidium atomic frequency standard. This combination provides Stratum-1 quality time distribution over WiFi with sub-microsecond stability.

## 1.1 Key Features

- Stratum-1 NTP server with rubidium reference (10⁻¹¹ stability)
- IEEE 1588 PTP support for precision timing applications
- WiFi connectivity via Pico 2-W's CYW43439 chip
- Web-based status and configuration interface
- PIO-based precision timing for sub-microsecond accuracy
- Automatic holdover during reference signal loss
- Five interval pulse outputs (0.5s, 1s, 6s, 30s, 60s) synchronized to atomic reference

# 2. FE-5680A Rubidium Oscillator

The FE-5680A is a compact rubidium atomic frequency standard originally designed for telecommunications. It provides an extremely stable 10MHz output signal locked to the hyperfine transition of rubidium-87 atoms.

## 2.1 Specifications

Parameter | Value | Notes
Output Frequency | 10 MHz | Sine wave
Output Level | ~1 Vpp | Into 50Ω
Short-term Stability | < 3×10⁻¹¹ | At 1 second
Long-term Stability | < 5×10⁻¹² | At 1 day
1PPS Output | NOT AVAILABLE | Derive from 10MHz
Supply (+15V) | 15V DC | Physics heater
Supply (+5V) | 5V DC | Electronics
Warmup Current | ~2A @ 15V | First 3-5 min
Operating Current | ~0.7A @ 15V | After warmup
Warmup Time | 3-5 minutes | To lock
Lock Indicator | Active LOW | Open collector

## 2.2 FE-5680A Pinout

Pin | Signal | Description
1 | +15V | Main power input
2 | GND | Ground
3 | LOCK | Lock status (4.8V/0.8V)
4 | +5V | Logic power
5 | GND | Ground
7 | 10MHz OUT | Sine wave (~1Vpp)
- | 1PPS | NOT AVAILABLE - derive from 10MHz

# 3. Signal Conditioning Circuit

The FE-5680A outputs a 10MHz sine wave at approximately 1Vpp, which must be converted to a 3.3V digital signal for the Pico 2-W. Note: Most FE-5680A units do NOT have a native 1PPS output - it must be derived from the 10MHz or sourced externally.

## 3.1 10MHz Sine to Square Converter

A high-speed comparator converts the 10MHz sine wave to a clean 3.3V square wave. The LT1016 or MAX999 are recommended for their fast propagation delay (<10ns).

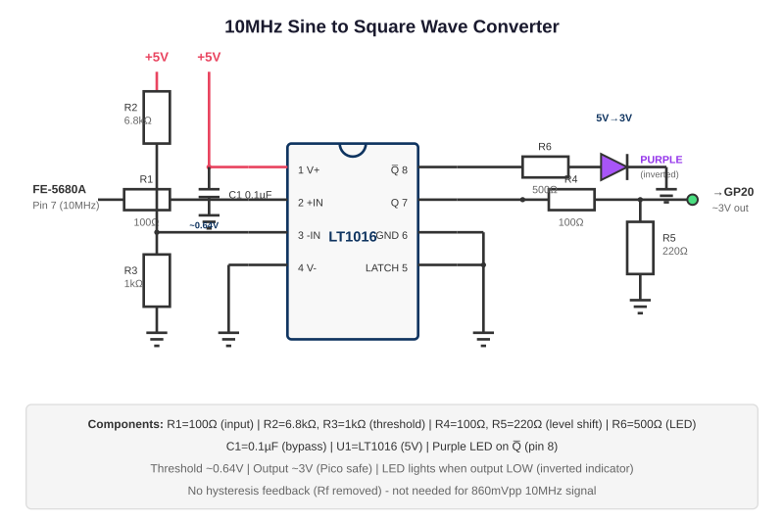
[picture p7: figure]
Sine to square converter

The circuit uses AC coupling (C1) to remove DC offset. R3 sets the threshold at ~1.65V. R1 provides pull-up for the open-drain output.

## 3.2 1PPS Signal (from divider or external)

Since most FE-5680A units don't have native 1PPS, derive it from 10MHz or use external GPS. If using a 5V external source, a voltage divider with Schottky diode provides level shifting and ESD protection.

5V to 3.3V divider

## 3.3 Lock Status Level Shifter

The FE-5680A lock output (Pin 3) is 4.8V when unlocked and 0.8V when locked. An NPN transistor (2N3904) inverts and level-shifts this signal to 3.3V logic, where HIGH indicates locked status.

NPN level shifter for lock status with LEDs

# 4. Power Supply Design

CHRONOS-Rb uses a universal AC mains input (100-240V AC, 50/60Hz) with isolated DC-DC conversion. The power supply provides +15V for the FE-5680A physics heater, +5V for logic, and +3.3V for digital/analog sections. An integrated zero-crossing detector enables AC mains frequency monitoring.

## 4.1 Power Specifications

Parameter | Value | Notes
AC Input | 100-240V AC | Universal mains
Frequency | 50/60 Hz | Auto-sensing
+15V Output | 3A max | FE-5680A heater
+5V Output | 1A max | Logic supply
+3.3V Digital | 500mA max | Pico, peripherals
+3.3V Analog | 100mA max | Low-noise, comparator
Isolation | 3kV reinforced | Mains to LV

## 4.2 AC to DC Conversion Chain

The power conversion follows this path from mains AC to regulated DC outputs:

1. IEC C14 Inlet: Standard fused inlet connector for 100-240VAC mains input
2. Fuse (2A slow-blow): Overcurrent protection on live conductor
3. EMI Filter + MOV: X2/Y1 capacitors, common-mode choke, MOV surge suppressor
4. Bridge Rectifier (GBU806): Full-wave rectification, 600V/8A rating
5. Bulk Capacitor (470µF/400V): Energy storage, produces 140-340V DC bus
6. Isolated Flyback Converter: Galvanic isolation, steps down to +15V @ 3A
7. LM2596 Buck Converter: 15V to 5V @ 1A switching regulator
8. AMS1117/LP5907 LDOs: 5V to 3.3V linear regulators (digital and low-noise analog)

## 4.3 Power Supply Block Diagram

The following diagram shows the complete AC-to-DC power conversion chain with isolation barrier between mains-voltage and low-voltage sections:

AC mains to DC power distribution with isolation

## 4.4 Zero-Crossing Detector Circuit

The H11AA1 is an AC-input optocoupler with back-to-back LEDs that detects both positive and negative zero crossings of the AC waveform. This provides galvanic isolation while allowing the Pico to measure mains frequency.

Circuit Description:

- AC Live connects through R1+R2 (2× 47kΩ in series, 94kΩ total) to H11AA1 pin 1
- AC Neutral connects to H11AA1 pin 2
- H11AA1 pin 4 (collector) connects to GP19 with 10kΩ pull-up to 3.3V
- H11AA1 pin 3 (emitter) connects to GND on the low-voltage side

The series resistors (R1+R2) limit LED current to ~2.5mA at 240VAC peak. Using two resistors in series provides adequate voltage rating for mains. The output produces a LOW pulse at each zero crossing.

Component | Value | Function
R1 | 47kΩ 1/2W | Current limit (mains side)
R2 | 47kΩ 1/2W | Current limit (mains side)
U1 | H11AA1 | AC-input opto, 5.3kV isolation
R3 | 10kΩ | Pull-up to 3.3V (LV side)
Output | GP19 | AC_ZERO_CROSS to Pico

Output Signal: Pulses at 2× mains frequency (100Hz for 50Hz mains, 120Hz for 60Hz mains). Firmware measures period between pulses to calculate actual mains frequency with ~0.001Hz resolution.

## 4.5 Safety Notes

- DANGER: This design involves hazardous mains voltage. Risk of electric shock or death.
- Use properly rated enclosure with strain relief for mains cable.
- Maintain 6mm minimum creepage between mains and low-voltage sections.
- The zero-crossing detector provides 5.3kV isolation - do not bypass or modify.
- FE-5680A physics package runs HOT. Ensure adequate ventilation.
- Never service with mains connected. Use isolation transformer for testing.
- Follow all local electrical codes and regulations.

# 5. Complete Wiring Guide

## 5.1 GPIO Assignments

GPIO | Function | Connection
GP2 | 1PPS Input | From level shifter
GP3 | 10MHz Input | From comparator
GP4 | Lock Status | From FE-5680A pin 9
GP6 | LED Sync | Green LED
GP7 | LED Network | Blue LED
GP8 | LED Activity | Yellow LED
GP9 | LED Error | Red LED
GP10 | Debug PPS | Test output
GP12/13 | I2C | Optional OLED
GP14 | Pulse 0.5s | 500ms interval
GP15 | Pulse 1s | 1 second interval
GP16 | Pulse 6s | 6 second interval
GP17 | Pulse 30s | 30 second interval
GP18 | Pulse 60s | 60 second interval
GP19 | AC Zero-Cross | Mains frequency monitor

## 5.2 System Schematic

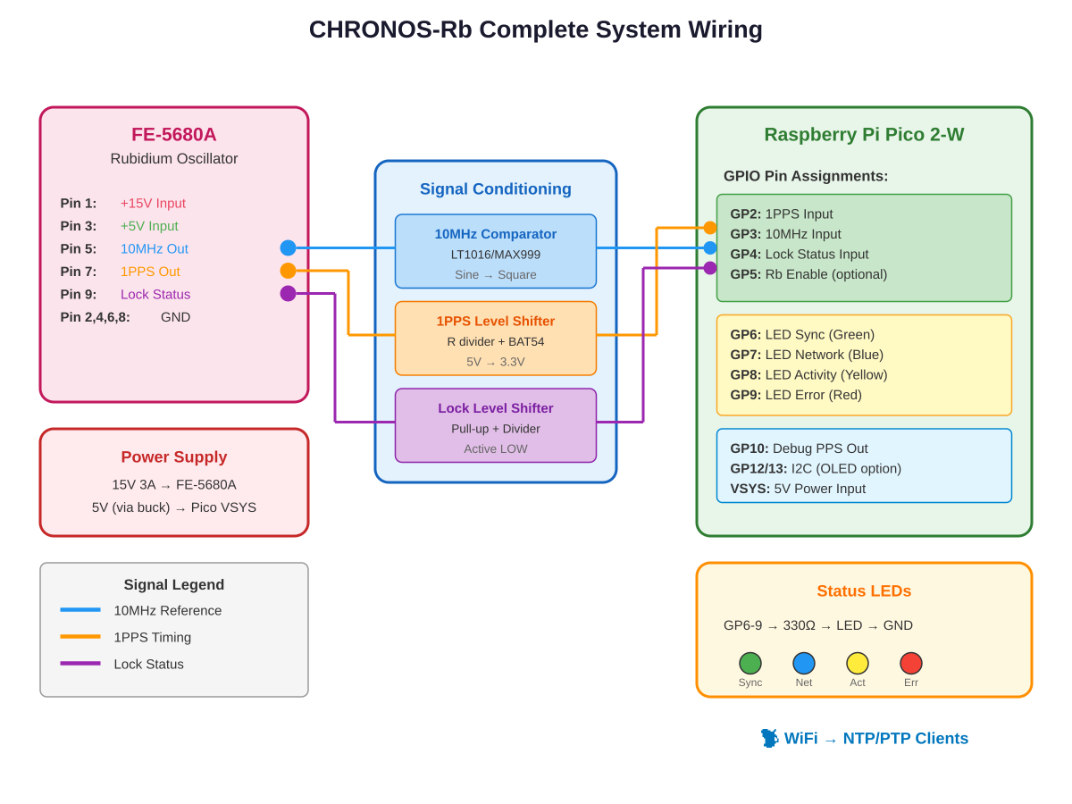
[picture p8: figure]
Complete system

## 5.3 Status LED Circuit

Four LEDs provide visual feedback. Each is driven through a 330Ω current-limiting resistor.

Status LEDs

## 5.4 Interval Pulse Outputs

CHRONOS-Rb provides five interval pulse outputs synchronized to the rubidium 1PPS reference. These outputs generate 10ms active-high pulses at precise intervals, useful for triggering external equipment, calibration, or timing distribution.

Timing outputs

Output | GPIO | Interval | Use Case
500ms | GP14 | 0.5 seconds | High-rate timing, servo sync
1s | GP15 | 1 second | PPS distribution
6s | GP16 | 6 seconds | GPS-compatible timing
30s | GP17 | 30 seconds | Calibration triggers
60s | GP18 | 60 seconds | Minute markers

All outputs are phase-locked to the atomic 1PPS reference and maintain sub-microsecond accuracy. The 0.5s output pulses twice per second (at 0ms and 500ms after each PPS edge). Use external buffers (e.g., 74LVC1G125) if driving cables or loads requiring more than 12mA.

# 6. Bill of Materials

## 6.1 Main Components

Qty | Description | Part Number | Notes
1 | Raspberry Pi Pico 2-W | SC1623 | With WiFi
1 | FE-5680A Rubidium | FE-5680A | Surplus/eBay
1 | 15V 3A PSU | - | Min 45W
1 | LT1016/MAX999 | LT1016CN8 | DIP-8

## 6.2 Signal Conditioning

Qty | Description | Value
2 | Resistor | 10kΩ 1%
1 | Resistor | 100Ω
1 | Resistor | 2.2kΩ
1 | Resistor | 3.3kΩ
4 | Resistor | 330Ω
1 | Capacitor | 100nF ceramic
1 | Diode | BAT54
4 | LEDs | 3mm assorted

# 7. Assembly Instructions

## 7.1 Preparation

9. Gather all components from the BOM
10. Test FE-5680A separately before integration
11. Program Pico with CHRONOS-Rb firmware
12. Prepare workspace with ESD protection

## 7.2 Assembly Steps

13. Build 10MHz comparator circuit on perfboard
14. Add bypass caps near comparator power pins
15. Build 1PPS voltage divider
16. Test each section before connecting to Pico
17. Connect D-sub to FE-5680A
18. Apply power and wait for lock (~5 min)
19. Verify signals with oscilloscope
20. Connect signal conditioning to Pico GPIOs

# 8. Firmware Overview

Build with Pico SDK 2.0+, CMake 3.13+, ARM GCC. Edit chronos_rb.h for WiFi credentials before building. Flash the UF2 file while holding BOOTSEL.

## 8.1 Module Overview

Module | File | Function
Main | main.c | Entry, init, loop
CLI | cli.c | Serial command interface
PPS | pps_capture.c | 1PPS timing
Freq | freq_counter.c | 10MHz measurement
AC Freq | ac_freq_monitor.c | Mains frequency monitor
Sync | rubidium_sync.c | State machine
Discipline | time_discipline.c | PI controller
Pulse | pulse_output.c | Configurable GPIO pulses
NTP | ntp_server.c | NTPv4 server
PTP | ptp_server.c | IEEE 1588
WiFi | wifi_manager.c | Connection mgmt
Web | web_interface.c | HTTP interface

# 9. Using the Time Server

## 9.1 NTP Client Setup

Linux: Add NTP=<ip> to /etc/systemd/timesyncd.conf

Windows: w32tm /config /manualpeerlist:<ip> /syncfromflags:manual /update

macOS: System Preferences > Date & Time, or: sudo sntp -sS <ip>

## 9.2 Web Interface

Access http://<device-ip>/ for real-time status. JSON API at /api/status for monitoring integration.

# 10. Troubleshooting

Symptom | Cause | Solution
No 10MHz | Power issue | Check +15V/+5V
Won't lock | Warmup | Wait 5+ minutes
No 1PPS | Not locked | Wait for lock LED
WiFi fail | Credentials | Check config
High offset | Signal issue | Check circuits
NTP timeout | Firewall | Open UDP 123

# Appendix: Project Name

CHRONOS-Rb =

- Compact
- High-precision
- Rubidium
- Oscillator
- Network
- Operating
- System

The "-Rb" suffix denotes rubidium (chemical symbol Rb). Chronos (Χρόνος) is the Greek personification of time.

— End of Document —

CHRONOS-Rb Hardware Documentation

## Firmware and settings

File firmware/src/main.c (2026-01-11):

/**
 * CHRONOS-Rb: Compact High-precision Rubidium Oscillator Network Operating System
 * 
 * Main entry point for Raspberry Pi Pico 2-W NTP/PTP Server
 * 
 * Copyright (c) 2025 - Open Source Hardware Project
 * License: MIT
 */

#include <stdio.h>
#include <string.h>
#include "pico/stdlib.h"
#include "pico/cyw43_arch.h"
#include "hardware/gpio.h"
#include "hardware/pio.h"
#include "hardware/clocks.h"
#include "hardware/timer.h"
#include "hardware/watchdog.h"

#include "chronos_rb.h"
#include "cli.h"
#include "pulse_output.h"
#include "ac_freq_monitor.h"
#include "config.h"
#include "log_buffer.h"
#include "ota_update.h"
#include "pps_generator.h"

/* Additional time protocol headers */
#include "time_protocol.h"
#include "nmea_output.h"
#include "radio_timecode.h"
#include "irig_b.h"
#include "roughtime.h"
#include "gptp.h"
#include "nts.h"
#include "gnss_input.h"

/*============================================================================
 * GLOBAL VARIABLES
 *============================================================================*/

volatile time_state_t g_time_state = {0};
volatile statistics_t g_stats = {0};
volatile bool g_wifi_connected = false;
volatile bool g_debug_enabled = false;

/* WiFi auto-connect state machine */
typedef enum {
    WIFI_AUTO_IDLE = 0,
    WIFI_AUTO_PENDING,
    WIFI_AUTO_CONNECTING,
    WIFI_AUTO_DONE
} wifi_auto_state_t;

static wifi_auto_state_t wifi_auto_state = WIFI_AUTO_IDLE;
static uint32_t wifi_auto_start_time = 0;

/*============================================================================
 * INITIALIZATION
 *============================================================================*/

/**
 * Initialize all GPIO pins
 */
void gpio_init_all(void) {
    /* Initialize 1PPS input with pull-down */
    gpio_init(GPIO_PPS_INPUT);
    gpio_set_dir(GPIO_PPS_INPUT, GPIO_IN);
    gpio_pull_down(GPIO_PPS_INPUT);
    
    /* Initialize 10MHz input */
    gpio_init(GPIO_10MHZ_INPUT);
    gpio_set_dir(GPIO_10MHZ_INPUT, GPIO_IN);
    
    /* Initialize Rubidium lock status input (HIGH=locked via NPN level shifter) */
    gpio_init(GPIO_RB_LOCK_STATUS);
    gpio_set_dir(GPIO_RB_LOCK_STATUS, GPIO_IN);
    /* External pull-up via NPN collector resistor - no internal pull needed */
    
    /* Note: GP5 now used for GPS UART RX, not Rb enable (always enabled) */

    /* Initialize debug outputs */
    gpio_init(GPIO_DEBUG_PPS_OUT);
    gpio_set_dir(GPIO_DEBUG_PPS_OUT, GPIO_OUT);
    gpio_put(GPIO_DEBUG_PPS_OUT, 0);

    /* Note: GPIO_GNSS_PPS_INPUT (GP11) is initialized by gnss_input_init() */

    /* Note: Pulse outputs (GP14-GP18) are now managed by pulse_output module */
}

/**
 * Initialize status LEDs
 */
void led_init(void) {
    gpio_init(GPIO_LED_SYNC);
    gpio_set_dir(GPIO_LED_SYNC, GPIO_OUT);
    gpio_put(GPIO_LED_SYNC, 0);
    
    gpio_init(GPIO_LED_NETWORK);
    gpio_set_dir(GPIO_LED_NETWORK, GPIO_OUT);
    gpio_put(GPIO_LED_NETWORK, 0);
    
    gpio_init(GPIO_LED_ACTIVITY);
    gpio_set_dir(GPIO_LED_ACTIVITY, GPIO_OUT);
    gpio_put(GPIO_LED_ACTIVITY, 0);
    
    gpio_init(GPIO_LED_ERROR);
    gpio_set_dir(GPIO_LED_ERROR, GPIO_OUT);
    gpio_put(GPIO_LED_ERROR, 0);
}

/**
 * LED control functions
 */
void led_set_sync(bool on) {
    gpio_put(GPIO_LED_SYNC, on);
}

void led_set_network(bool on) {
    gpio_put(GPIO_LED_NETWORK, on);
}

void led_set_activity(bool on) {
    gpio_put(GPIO_LED_ACTIVITY, on);
}

void led_set_error(bool on) {
    gpio_put(GPIO_LED_ERROR, on);
}

static uint32_t activity_off_time = 0;

void led_blink_activity(void) {
    gpio_put(GPIO_LED_ACTIVITY, 1);
    activity_off_time = time_us_32() + 50000;  /* 50ms pulse */
}

/**
 * Startup LED sequence for visual feedback
 */
static void led_startup_sequence(void) {
    const uint leds[] = {GPIO_LED_SYNC, GPIO_LED_NETWORK, GPIO_LED_ACTIVITY, GPIO_LED_ERROR};
    
    /* Sequential blink */
    for (int i = 0; i < 4; i++) {
        gpio_put(leds[i], 1);
        sleep_ms(100);
        gpio_put(leds[i], 0);
    }
    
    /* All on briefly */
    for (int i = 0; i < 4; i++) {
        gpio_put(leds[i], 1);
    }
    sleep_ms(200);
    for (int i = 0; i < 4; i++) {
        gpio_put(leds[i], 0);
    }
}

/**
 * Print startup banner
 */
static void print_banner(void) {
    printf("\n");
    printf("╔══════════════════════════════════════════════════════════════╗\n");
    printf("║                      CHRONOS-Rb v%s                       ║\n", CHRONOS_VERSION_STRING);
    printf("║  Compact High-precision Rubidium Oscillator Network System   ║\n");
    printf("║                                                              ║\n");
    printf("║  Raspberry Pi Pico 2-W NTP/PTP Server                        ║\n");
    printf("║  Synchronized to FE-5680A Rubidium Frequency Standard        ║\n");
    printf("╚══════════════════════════════════════════════════════════════╝\n");
    printf("\n");
    printf("Build: %s %s\n", CHRONOS_BUILD_DATE, CHRONOS_BUILD_TIME);
    printf("System Clock: %lu MHz\n", clock_get_hz(clk_sys) / 1000000);
    printf("\n");
}

/**
 * Main system initialization
 */
void chronos_init(void) {
    /* Initialize stdio for debug output */
    stdio_init_all();

    /* Initialize log buffer to capture printf output for web interface */
    log_buffer_init();

    /* Small delay for USB enumeration */
    sleep_ms(2000);

    print_banner();
    
    printf("[INIT] Initializing GPIO...\n");
    gpio_init_all();
    
    printf("[INIT] Initializing LEDs...\n");
    led_init();
    led_startup_sequence();
    
    printf("[INIT] Initializing time subsystem...\n");
    time_init();
    
    printf("[INIT] Initializing PPS capture...\n");
    pps_capture_init();
    
    printf("[INIT] Initializing frequency counter...\n");
    freq_counter_init();

    printf("[INIT] Initializing 1PPS generator (10MHz / 10,000,000)...\n");
    pps_generator_init();
    pps_generator_start();

    printf("[INIT] Initializing time discipline...\n");
    discipline_init();
    
    printf("[INIT] Initializing rubidium sync...\n");
    rubidium_sync_init();
    
    printf("[INIT] Initializing configuration...\n");
    config_init();

    printf("[INIT] Initializing WiFi...\n");
    wifi_init();

    printf("[INIT] Initializing pulse outputs...\n");
    pulse_output_init();

    printf("[INIT] Initializing CLI...\n");
    cli_init();

    printf("[INIT] Initializing OTA subsystem...\n");
    ota_init();

    printf("[INIT] Initializing NMEA output...\n");
    nmea_output_init();

    printf("[INIT] Initializing radio timecode outputs...\n");
    radio_timecode_init();

    /* GNSS input must be initialized BEFORE AC frequency monitor because
     * gnss_input_init() registers the shared GPIO callback that handles
     * both GNSS PPS (GP11) and AC zero crossing (GP19) interrupts */
    printf("[INIT] Initializing GNSS receiver input...\n");
    gnss_input_init();

    printf("[INIT] Initializing AC frequency monitor...\n");
    ac_freq_init();

    /* Apply RF, NMEA, and GNSS settings from config */
    {
        config_t *cfg = config_get();
        printf("[INIT] Applying RF/NMEA/GNSS settings from config...\n");
        radio_timecode_enable(RADIO_DCF77, cfg->rf_dcf77_enabled);
        radio_timecode_enable(RADIO_WWVB, cfg->rf_wwvb_enabled);
        radio_timecode_enable(RADIO_JJY40, cfg->rf_jjy40_enabled);
        radio_timecode_enable(RADIO_JJY60, cfg->rf_jjy60_enabled);
        nmea_output_enable(cfg->nmea_enabled);
        gnss_enable(cfg->gnss_enabled);
        printf("[INIT]   DCF77: %s, WWVB: %s, JJY40: %s, JJY60: %s\n",
               cfg->rf_dcf77_enabled ? "ON" : "OFF",
               cfg->rf_wwvb_enabled ? "ON" : "OFF",
               cfg->rf_jjy40_enabled ? "ON" : "OFF",
               cfg->rf_jjy60_enabled ? "ON" : "OFF");
        printf("[INIT]   NMEA: %s, GNSS: %s\n",
               cfg->nmea_enabled ? "ON" : "OFF",
               cfg->gnss_enabled ? "ON" : "OFF");
    }

    /* IRIG-B disabled - causes crashes, needs debugging
    printf("[INIT] Initializing IRIG-B output...\n");
    irig_b_init();
    */

    /* Check for WiFi auto-connect */
    if (config_wifi_auto_connect_enabled()) {
        config_t *cfg = config_get();
        printf("[INIT] WiFi auto-connect enabled for '%s'\n", cfg->wifi_ssid);
        wifi_auto_state = WIFI_AUTO_PENDING;
    }

    printf("[INIT] Initialization complete!\n\n");
}

/*============================================================================
 * WIFI AUTO-CONNECT (NON-BLOCKING)
 *============================================================================*/

/**
 * Non-blocking WiFi auto-connect task
 * Called from main loop to handle WiFi connection in background
 */
static void wifi_auto_connect_task(void) {
    switch (wifi_auto_state) {
        case WIFI_AUTO_IDLE:
        case WIFI_AUTO_DONE:
            /* Nothing to do */
            break;

        case WIFI_AUTO_PENDING:
            /* Start connection attempt */
            {
                config_t *cfg = config_get();
                printf("[WIFI] Auto-connecting to '%s'...\n", cfg->wifi_ssid);
                wifi_auto_start_time = time_us_32();
                wifi_auto_state = WIFI_AUTO_CONNECTING;

                /* Initiate connection (now non-blocking with internal watchdog feeding) */
                if (wifi_connect(cfg->wifi_ssid, cfg->wifi_pass)) {
                    printf("[WIFI] Auto-connect successful!\n");
                    char ip_str[16];
                    get_ip_address_str(ip_str, sizeof(ip_str));
                    printf("[WIFI] IP Address: %s\n", ip_str);

                    g_wifi_connected = true;
                    ntp_server_init();
                    ptp_server_init();
                    web_init();
                    /* Disabled - all cause crashes after WiFi connect:
                    time_protocols_init();
                    roughtime_init();
                    gptp_init();
                    nts_init();
                    */
                    extern void wifi_mark_services_started(void);
                    wifi_mark_services_started();
                    printf("[WIFI] Network services started\n");
                    wifi_auto_state = WIFI_AUTO_DONE;
                } else {
                    printf("[WIFI] Auto-connect failed\n");
                    wifi_auto_state = WIFI_AUTO_DONE;
                }
            }
            break;

        case WIFI_AUTO_CONNECTING:
            /* Check for timeout (shouldn't reach here with current blocking connect) */
            if (time_us_32() - wifi_auto_start_time > 30000000) {  /* 30 second timeout */
                printf("[WIFI] Auto-connect timeout\n");
                wifi_auto_state = WIFI_AUTO_DONE;
            }
            break;
    }
}

/*============================================================================
 * MAIN LOOP
 *============================================================================*/

/**
 * Update LED states based on system status
 */
static void update_status_leds(void) {
    /* Sync LED: solid when locked, blinking when acquiring */
    static uint32_t sync_blink_time = 0;
    static bool sync_blink_state = false;
    
    if (g_time_state.sync_state == SYNC_STATE_LOCKED) {
        led_set_sync(true);
    } else if (g_time_state.sync_state >= SYNC_STATE_FREQ_CAL) {
        if (time_us_32() > sync_blink_time) {
            sync_blink_state = !sync_blink_state;
            led_set_sync(sync_blink_state);
            sync_blink_time = time_us_32() + 500000;  /* 500ms blink */
        }
    } else {
        led_set_sync(false);
    }
    
    /* Network LED */
    led_set_network(g_wifi_connected);
    
    /* Activity LED auto-off */
    if (activity_off_time && time_us_32() > activity_off_time) {
        gpio_put(GPIO_LED_ACTIVITY, 0);
        activity_off_time = 0;
    }
    
    /* Error LED */
    led_set_error(g_time_state.sync_state == SYNC_STATE_ERROR);
}

/**
 * Print periodic status (only when debug enabled)
 */
static void print_status(void) {
    if (!g_debug_enabled) {
        return;
    }

    static uint32_t last_status_time = 0;

    if (time_us_32() - last_status_time > 10000000) {  /* Every 10 seconds */
        last_status_time = time_us_32();

        const char *sync_states[] = {
            "INIT", "FREQ_CAL", "COARSE", "FINE", "LOCKED", "HOLDOVER", "ERROR"
        };

        printf("\n[STATUS] Sync: %s | Rb Lock: %s | PPS: %lu | Freq: %lu Hz\n",
               sync_states[g_time_state.sync_state],
               g_time_state.rb_locked ? "YES" : "NO",
               g_time_state.pps_count,
               g_time_state.last_freq_count);

        printf("[STATUS] Offset: %lld ns | Freq Offset: %.3f ppb\n",
               g_time_state.offset_ns,
               g_time_state.frequency_offset);

        printf("[STATUS] NTP Requests: %lu | PTP Sync: %lu | Errors: %lu\n",
               g_stats.ntp_requests,
               g_stats.ptp_sync_sent,
               g_stats.errors);

        if (g_wifi_connected) {
            extern uint32_t get_ip_address(void);
            uint32_t ip = get_ip_address();
            printf("[STATUS] IP: %lu.%lu.%lu.%lu\n",
                   ip & 0xFF, (ip >> 8) & 0xFF,
                   (ip >> 16) & 0xFF, (ip >> 24) & 0xFF);
        }
    }
}

/**
 * Main entry point
 */
int main(void) {
    /* Set system clock to 150MHz for better timing resolution */
    set_sys_clock_khz(150000, true);

    /* Initialize everything */
    chronos_init();

    /* WiFi connection message */
    if (wifi_auto_state != WIFI_AUTO_PENDING) {
        printf("[WIFI] Use 'wifi <SSID> <PWD>' command to connect\n");
    }

    printf("\n[MAIN] Entering main loop...\n\n");

    /* Enable watchdog with 8 second timeout */
    watchdog_enable(8000, 1);

    /* OTA boot confirmation timer - confirm after 60 seconds of stable operation */
    static bool ota_boot_confirmed = false;
    uint32_t ota_confirm_time = time_us_32() + 60000000;  /* 60 seconds */
    
    /* Main loop */
    while (1) {
        /* Feed watchdog */
        watchdog_update();

        /* OTA boot confirmation - confirm after 60 seconds of stable operation */
        if (!ota_boot_confirmed && time_us_32() >= ota_confirm_time) {
            ota_confirm_boot();
            ota_boot_confirmed = true;
        }

        /* Run all tasks */
        rubidium_sync_task();

        /* Poll PPS capture FIFOs for offset measurement */
        freq_counter_pps_task();

        /* WiFi auto-connect (non-blocking) */
        wifi_auto_connect_task();

        /* WiFi task handles reconnection - call always */
        wifi_task();

        if (g_wifi_connected) {
            ntp_server_task();
            ptp_server_task();
            web_task();
            ota_task();
            /* gptp_task(); - disabled */
        }

        /* Time output tasks */
        nmea_output_task();
        radio_timecode_task();
        /* irig_b_task(); - disabled, crashes */

        /* GNSS input task */
        gnss_input_task();
        
        /* Update status LEDs */
        update_status_leds();
        
        /* Process configurable pulse outputs */
        pulse_output_task();

        /* Process AC frequency monitor */
        ac_freq_task();

        /* Process CLI input */
        cli_task();

        /* Print periodic status */
        print_status();

        /* Small delay to prevent tight loop */
        sleep_us(100);
    }
    
    return 0;
}

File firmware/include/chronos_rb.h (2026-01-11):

/**
 * CHRONOS-Rb: Compact High-precision Rubidium Oscillator Network Operating System
 * 
 * Main configuration header for Raspberry Pi Pico 2-W NTP/PTP Server
 * synchronized to FE-5680A Rubidium Frequency Standard
 * 
 * Copyright (c) 2025 - Open Source Hardware Project
 * License: MIT
 */

#ifndef CHRONOS_RB_H
#define CHRONOS_RB_H

#include <stdint.h>
#include <stdbool.h>

/*============================================================================
 * VERSION INFORMATION
 *============================================================================*/
#define CHRONOS_VERSION_MAJOR   1
#define CHRONOS_VERSION_MINOR   4
#define CHRONOS_VERSION_PATCH   69
#define CHRONOS_VERSION_STRING  "1.4.69"
#define CHRONOS_BUILD_DATE      __DATE__
#define CHRONOS_BUILD_TIME      __TIME__

/*============================================================================
 * GPIO PIN DEFINITIONS - Raspberry Pi Pico 2-W
 *============================================================================*/

/* FE-5680A 1PPS Input (active high, from external FE-5680A source) */
#define GPIO_FE_PPS_INPUT       21      /* GP21 - 1PPS from FE-5680A */
#define GPIO_PPS_INPUT          GPIO_FE_PPS_INPUT  /* Primary PPS source */

/* FE-5680A 10MHz Reference Input (after comparator, 3.3V LVCMOS) */
#define GPIO_FE_10MHZ_INPUT     20      /* GP20 - FE-5680A 10MHz reference */
#define GPIO_10MHZ_INPUT        GPIO_FE_10MHZ_INPUT  /* Primary 10MHz source */

/* FE-5680A Status/Control Lines */
#define GPIO_RB_LOCK_STATUS     22      /* GP22 - Rubidium lock indicator (HIGH=locked) */

/* Status LEDs */
#define GPIO_LED_SYNC           6       /* GP6 - Green: Synchronized to Rb */
#define GPIO_LED_NETWORK        7       /* GP7 - Blue: Network connected */
#define GPIO_LED_ACTIVITY       8       /* GP8 - Yellow: NTP/PTP activity */
#define GPIO_LED_ERROR          9       /* GP9 - Red: Error condition */

/* Debug/Diagnostic Outputs */
#define GPIO_DEBUG_PPS_OUT      10      /* GP10 - Regenerated 1PPS for test */

/* GNSS Receiver Input (u-blox NEO-M8N, M9N, or similar) */
#define GPIO_GNSS_PPS_INPUT     11      /* GP11 - GNSS 1PPS input (backup time source) */

/* UART for Debug (optional) */
#define GPIO_UART_TX            0       /* GP0 - UART0 TX */
#define GPIO_UART_RX            1       /* GP1 - UART0 RX */

/* I2C for optional OLED display */
#define GPIO_I2C_SDA            12      /* GP12 - I2C0 SDA */
#define GPIO_I2C_SCL            13      /* GP13 - I2C0 SCL */

/* Interval Pulse Outputs (active high, ~10ms pulse width) */
#define GPIO_PULSE_500MS        14      /* GP14 - 0.5 second interval pulse */
#define GPIO_PULSE_1S           15      /* GP15 - 1 second interval pulse */
#define GPIO_PULSE_6S           16      /* GP16 - 6 second interval pulse */
#define GPIO_PULSE_30S          17      /* GP17 - 30 second interval pulse */
#define GPIO_PULSE_60S          18      /* GP18 - 60 second interval pulse */

/* AC Mains Frequency Monitor Input */
#define GPIO_AC_ZERO_CROSS      19      /* GP19 - Zero-crossing detector input */

/* Radio Timecode Outputs (simulated LF radio signals) */
#define GPIO_DCF77              2       /* GP2 - DCF77 Germany 77.5kHz */
#define GPIO_WWVB               3       /* GP3 - WWVB USA 60kHz */
#define GPIO_JJY40              4       /* GP4 - JJY Japan 40kHz (Fukushima) */
#define GPIO_JJY60              26      /* GP26 - JJY Japan 60kHz (Kyushu) */

/* IRIG-B Timecode Output */
#define GPIO_IRIG_B             27      /* GP27 - IRIG-B timecode */

/* NMEA/GNSS Serial (UART1) */
#define GPIO_GNSS_TX            4       /* GP4 - UART1 TX (commands to GNSS module) */
#define GPIO_GNSS_RX            5       /* GP5 - UART1 RX (NMEA from GNSS module) */

/* Interval pulse timing */
#define PULSE_WIDTH_MS          10      /* Output pulse width in milliseconds */

/*============================================================================
 * TIMING CONSTANTS
 *============================================================================*/

/* System clock configuration */
#define SYSTEM_CLOCK_HZ         150000000UL     /* 150 MHz system clock */
#define REF_CLOCK_HZ            10000000UL      /* 10 MHz rubidium reference */

/* PPS timing parameters */
#define PPS_NOMINAL_PERIOD_US   1000000UL       /* 1 second in microseconds */
#define PPS_TOLERANCE_US        100             /* ±100µs tolerance for lock */
#define PPS_PULSE_MIN_US        10              /* Minimum valid pulse width */
#define PPS_PULSE_MAX_US        500             /* Maximum valid pulse width */

/* Frequency counter parameters */
#define FREQ_GATE_TIME_MS       1000            /* 1 second gate time */
#define FREQ_NOMINAL_COUNT      10000000UL      /* Expected count in gate time */
#define FREQ_TOLERANCE_PPB      1000            /* ±1000 ppb tolerance */

/* Time discipline parameters */
#define DISCIPLINE_TAU_FAST     64              /* Fast time constant (seconds) */
#define DISCIPLINE_TAU_SLOW     1024            /* Slow time constant (seconds) */
#define DISCIPLINE_GAIN_P       0.7             /* Proportional gain */
#define DISCIPLINE_GAIN_I       0.3             /* Integral gain */

/* GNSS receiver parameters */
#define GPS_UART_BAUD           115200          /* GNSS module baud rate */
#define GPS_PPS_TIMEOUT_MS      2000            /* GNSS PPS timeout (2 seconds) */
#define GPS_NMEA_TIMEOUT_MS     5000            /* NMEA sentence timeout */
#define GPS_MIN_SATS            4               /* Minimum satellites for valid fix */

/*============================================================================
 * NETWORK CONFIGURATION
 *============================================================================*/

/* WiFi defaults (can be overridden via web interface) */
#define WIFI_SSID_DEFAULT       "CHRONOS-Rb"
#define WIFI_PASS_DEFAULT       "rubidium123"
#define WIFI_COUNTRY            "US"

/* NTP Server Configuration */
#define NTP_PORT                123
#define NTP_VERSION             4
#define NTP_STRATUM             1               /* Stratum 1 - Primary reference */
#define NTP_POLL_MIN            4               /* 16 seconds minimum */
#define NTP_POLL_MAX            10              /* 1024 seconds maximum */
#define NTP_PRECISION           -20             /* ~1 microsecond precision */
#define NTP_REFID               "RBDM"          /* Rubidium reference ID */

/* PTP (IEEE 1588) Configuration */
#define PTP_EVENT_PORT          319
#define PTP_GENERAL_PORT        320
#define PTP_DOMAIN              0
#define PTP_PRIORITY1           128
#define PTP_PRIORITY2           128
#define PTP_CLOCK_CLASS         6               /* Primary reference source */
#define PTP_CLOCK_ACCURACY      0x21            /* 100ns accuracy class */

/* Web Interface */
#define WEB_PORT                80
#define WEB_MAX_CONNECTIONS     4
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

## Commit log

2025-12-20 MAESTRO: Create KiCad project directory structure
    Created hardware/kicad/ directory with subdirectories:
    - symbols/ - for custom schematic symbols
    - footprints/ - for custom PCB footprints
    - 3dmodels/ - for 3D component models
    - gerbers/ - for manufacturing output files
    Added .gitkeep files to track empty directories.
2025-12-20 MAESTRO: Complete Phase 01 KiCad project setup with hierarchical schematics
    Created complete KiCad 8.0 project infrastructure for CHRONOS-Rb:
    - Main project file with JLCPCB-compatible design rules (6mil trace/space)
    - Top-level schematic with hierarchical sheet symbols and signal flow documentation
    - Four sub-schematics: Power Supply, Signal Conditioning, Pico Interface, Connectors
    - Custom symbol library (chronos_rb.kicad_sym) with placeholder
    - Custom footprint library directory (chronos_rb.pretty)
    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
    [chronos_rb.kicad_sch, connectors.kicad_sch, pico_interface.kicad_sch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]
2025-12-20 Add KiCad files, Auto Run Docs, and .gitignore
    - Add Phase 02-05 documentation for signal conditioning, power supply,
    Pico interface, and PCB layout
    - Update KiCad project file
    - Create .gitignore for KiCad local files and build artifacts
2025-12-20 Fix build errors for lwIP and missing declarations
    - Add lwipopts.h for lwIP configuration on Pico W
    - Add missing includes (math.h, hardware/sync.h) to rubidium_sync.c
    - Add missing function prototypes to chronos_rb.h
    - Remove duplicate htonl/ntohl definitions from ntp_server.c (provided by lwIP)
    - Fix wifi_manager.c to use netif_default instead of netif_list
    [chronos_rb.h, rubidium_sync.c]
2025-12-23 Add CLI, persistent config, AC frequency monitor, and pulse outputs
    Features:
    - USB CLI with commands: help, status, pins, acfreq, debug, config, wifi, pulse, reboot
    - Persistent flash configuration with CRC32 validation (config save/show/reset)
    - WiFi auto-connect on boot using saved credentials
    - AC mains frequency monitor via zero-crossing detector (GP19)
    - Configurable pulse outputs with interval/second/minute/time modes
    - Debug on/off command to control periodic status output
    Fixes:
    - Watchdog timeout during 30s WiFi connect (extend to 35s during connect)
    - Flash write safety with PICO_FLASH_ASSUME_CORE1_SAFE for CYW43 compatibility
    Build:
    - Added make flash target with automatic boot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
    [power_supply.kicad_sch]
2025-12-23 Fix web server and add duplicate init protection
    - Fixed tcp_write ERR_MEM by increasing TCP_SND_BUF to 4*TCP_MSS (5840 bytes)
    - Increased MEM_SIZE to 8000 for larger TCP buffers
    - Added "already running" guards to ntp_server_init, ptp_server_init, web_init
    - Fixed format specifier mismatch in HTML generation (uint64_t vs unsigned long)
    - Show actual IP address in web server init log messages
    [cli.c]
2025-12-25 Add web config page, unified CLI, and fix WiFi connection crashes
    - Add config page with WiFi settings, CLI window, and pulse outputs
    - Unify USB and HTTP CLI using cli_execute() with buffer output
    - Add AC frequency monitor and pulse outputs to status page
    - Fix WiFi crash on failed connections using async connect with
    manual polling and watchdog feeding instead of blocking timeout
    - Add quoted string support for WiFi SSID with spaces in CLI
    [cli.c, main.c]
2025-12-31 Update FE-5680A pinout and add NPN level shifter for lock detection
    - Correct DB-9 pinout: Pin 1 (+15V), Pin 2 (GND), Pin 3 (Lock),
    Pin 4 (+5V), Pin 5 (GND), Pin 7 (10MHz)
    - Add NPN transistor (2N3904) level shifter circuit for lock status:
    22k input resistor, 10k base-to-GND, 10k collector pull-up
    - FE-5680A outputs 4.8V (unlocked) / 0.8V (locked)
    - Transistor inverts signal: GPIO HIGH = locked, LOW = unlocked
    - Update firmware to remove signal inversion in check_rb_lock()
    - Remove internal pull-up (external pull-up via collector resistor)
    - Update all documentation and schematics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
    [connectors.kicad_sch, signal_conditioning.kicad_sch]
2025-12-31 Fix 1PPS documentation: FE-5680A DB-9 has no native 1PPS output
    Most FE-5680A units (including the DB-9 +15V/+5V version) do NOT have a native
    1PPS output - only 10MHz. Updated all documentation and code comments to reflect
    that 1PPS must be derived from the 10MHz reference using a divider circuit, or
    sourced from an external GPS/GNSS receiver.
    Changes:
    - Updated firmware comments (pps_capture.c, chronos_rb.h, cli.c)
    - Fixed FE-5680A pinout in all documentation (DB-9: Pin 1=+15V, Pin 2=GND,
    Pin 3=Lock, Pin 4=+5V, Pin 5=GND, Pin 7=10MHz)
    - Updated signal flow diagrams and block diagrams
    - Changed 1PPS level shifter references to indicate it's for external sources
    - Fixed KiCad schematic de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
    [chronos_rb.kicad_sch]
2025-12-31 Add 1PPS divider and lock detect circuits to README
    Added required signal conditioning circuits:
    1PPS Generation (required - FE-5680A has no native 1PPS):
    - Option 1: 7x 74HC4017 decade counter chain (÷10,000,000)
    - Option 2: External GPS module with level shifter
    Lock Status Level Shifter:
    - 2N3904 NPN transistor circuit
    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
2025-12-31 Use 74HC390 dual decade counter for 1PPS divider (4 chips vs 7)
    Changed from 7× 74HC4017 to 4× 74HC390 dual decade counters.
    Each 74HC390 has two ÷10 stages, so 4 chips give ÷10,000,000.
2025-12-31 Add lock detector SVG diagram
    New hardware/lock_detector.svg showing the 2N3904 NPN transistor
    level shifter circuit for FE-5680A lock status detection.
2025-12-31 Add lock detector diagram to docx documentation
    - Created lock_detector.png from SVG
    - Added section 3.3 "Lock Status Level Shifter" to create_documentation_v2.js
    - Shows 2N3904 NPN transistor circuit with R6/R7/R8 values
2025-12-31 Add red/green LEDs to lock detector circuit
    - Green LED lights when locked (collector HIGH → current to GND)
    - Red LED lights when unlocked (collector LOW → current from 3.3V)
    - Added R9/R10 (330Ω) current limiting resistors
    - Fixed diagram: title overlap, added B/C/E pin labels
    - Updated README and regenerated docx
2026-01-01 Update lock detector: R8 to 1kΩ, yellow LED, cleaner layout
    - Changed R8 pull-up from 10kΩ to 1kΩ for proper LED drive current
    - Changed red LED to yellow LED
    - Reorganized SVG to move yellow LED 3.3V connection to bottom
2026-01-01 Replace hardware 1PPS divider with GPS module requirement
    - Remove 74HC390 divider chain option
    - Add u-blox NEO-6M as recommended GPS module (~$10-15)
    - GPS provides UTC-aligned 1PPS and time-of-day via NMEA
    - Firmware counts 10MHz cycles, verifies against GPS 1PPS
    - Update block diagram to show GPS integration
    - Add GP0/GP1 for GPS UART connection
    - Change red LED to yellow LED in lock detector
2026-01-01 Move lock status to GP22 (5V tolerant), add GPS requirement
    - Changed lock status GPIO from GP28 (ADC) to GP22 (5V tolerant)
    - Removed hardware 1PPS divider option
    - GPS module now required for UTC-aligned 1PPS
    - Recommended u-blox NEO-6M/8M modules
    - Added GP0/GP1 for GPS UART connection
    - Freed GP4/GP5 for optional I2C OLED display
2026-01-01 Add OTA firmware update support with A/B partitioning
    - Integrate pico_fota_bootloader for A/B partition updates with rollback
    - Add AES-128 encryption for OTA images (key auto-generated, gitignored)
    - Create ota_update.c/h module with chunked upload API
    - Add /ota web page with file upload and progress tracking
    - Add /api/ota/* endpoints (begin, chunk, finish, apply, status)
    - Boot confirmation after 60s prevents bricking (auto-rollback on failure)
    - Fix aes_encrypt.py to support both Crypto and Cryptodome imports
    Build outputs:
    - pico_fota_bootloader.uf2: Flash first (bootloader)
    - chronos_rb.uf2: Flash second (application)
    - chronos_rb_fota_image_encrypted.bin: For OTA updates
    🤖 Gene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
    [main.c]
2026-01-01 Add flash targets for bootloader and application
    - make flash-bootloader: Flash FOTA bootloader (first time only)
    - make flash-app: Flash application firmware
    - make flash-initial: Flash both bootloader + app (new devices)
    - make flash: Same as flash-app (for OTA-capable devices)
    - Post-build message shows OTA update file location
2026-01-02 Fix lock detector diagram - yellow LED connects to collector
    Fixed incorrect wiring in lock status level shifter diagram:
    - Yellow LED was incorrectly shown connected from GND to +3.3V
    - Now correctly shows yellow LED connected from collector to +3.3V
    - When collector LOW (unlocked): current flows +3.3V → LED → collector
    - When collector HIGH (locked): no current flows, LED off
    Updated: README.md, lock_detector.svg, lock_detector.png, Hardware_Guide.docx
2026-01-02 Add blue LED signal indicator to 10MHz comparator circuit
    - Add R4 (1kΩ) and blue LED to comparator output
    - LED glows when 10MHz signal is present (appears solid due to speed)
    - Update SVG, PNG, and docx documentation
    - Update README with new schematic and component list
2026-01-03 Fix 10MHz comparator circuit for FE-5680A
    - Update circuit to work with actual FE-5680A output (~860mVpp at 0.7V DC)
    - Use 6.8kΩ/1kΩ voltage divider for ~0.64V threshold at -IN
    - Use 100Ω/220Ω level shifter for 5V→3V output (prevents RC filtering)
    - Move LED to Q̅ (pin 8) to reduce loading on Q output
    - Remove hysteresis feedback (not needed for this signal level)
    - Update schematic SVG, PNG, docx, README, and CLAUDE.md
    Components: R1=100Ω, R2=6.8kΩ, R3=1kΩ, R4=100Ω, R5=220Ω, R6=500Ω, C1=0.1µF
2026-01-03 Move 10MHz input from GP3 to GP20
    Relocates 10MHz frequency counter input to the other side of the Pico:
    - GP3 → GP20
    Updated files:
    - firmware/include/chronos_rb.h
    - README.md
    - CLAUDE.md
    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
2026-01-04 Add PPS generator, fix OTA encryption, bump to v1.0.3
    - Add PPS generator module that counts 10MHz falling edges to produce 1PPS
    - Fix OTA build to always generate encrypted firmware images
    (PFB_WITH_IMAGE_ENCRYPTION was incorrectly OFF)
    - Fix PPS timing from ~1.5Hz to exactly 1Hz using falling edge detection
    - Regenerate comparator schematic PNG with purple LED indicator
    [chronos_rb.h, freq_counter.c, main.c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]
2026-01-05 Add OTA upload script, fix freq counter, move FE-5680A pins to GP20/21
    - Add ota.sh script and `make fota` target for OTA updates
    - Fix freq_counter PIO: use `mov x, ~null` to start at 0xFFFFFFFF
    - Remove pio_gpio_init for input pins (PIOs can read any GPIO)
    - Add timeout detection in freq_counter_signal_present()
    - Move FE-5680A 1PPS input from GP2 to GP21
    - Move FE-5680A 10MHz input from GP3 to GP20
    - Add freq_measurements to JSON API
    - Bump version to 1.0.8
    [chronos_rb.h, cli.c, freq_counter.c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]
2026-01-05 Fix PPS period calculation using wrong timestamp
    The period calculation was using prev_pps_timestamp_us which held
    the timestamp from TWO pulses ago, not the previous pulse. This
    caused period to be ~2 seconds instead of ~1 second, failing the
    ±100µs tolerance check and preventing sync state progression.
    Fix: Use pps_timestamp_us (current timestamp at start of handler)
    for period calculation instead of the redundant prev variable.
    This allows the sync state machine to progress through FREQ_CAL →
    COARSE → FINE → LOCKED, enabling stratum 1 NTP operation.
    - Bump version to 1.0.10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
    [chronos_rb.h, pps_capture.c]
2026-01-05 Add web config page, unified CLI, and fix WiFi connection crashes
    Web Interface (v1.2.4):
    - Add time display with conditional coloring (green=valid, red=invalid)
    - Add logo status indicator (green=all OK, red=error)
    - Add RF Outputs card showing DCF77/WWVB/JJY40/JJY60 status
    - Add POST /api/rf endpoint for toggling RF outputs
    - Fix JSON buffer overflow (512→768 bytes) that caused OTA crashes
    CLI Commands:
    - Add 'rf' command to view/toggle radio timecode outputs
    - Add 'nmea' command to view/toggle NMEA serial output
    - All settings persist to flash and load at boot
    Configuration:
    - Bump config version to 2 with migration from v1
    - Add rf_dcf77_enabled, rf_wwvb_enabled, rf_jjy40_enabled, rf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
    [chronos_rb.h, cli.c, irig_b.c]
2026-01-05 Add GPS receiver input for backup timing (NEO-M8N on GP5/GP11)
    - Add gps_input module with NMEA parsing (GPRMC, GPGGA, GPGSA, GPZDA)
    - Capture GPS PPS on GP11 via GPIO callback (separate from Rb PIO)
    - Repurpose GP5 (was Rb enable) for GPS UART1 RX
    - Add GPS status to web interface and JSON API with diagnostics
    - Add GPS CLI command for status and enable/disable
    - Add GPS fallback in rubidium_sync for holdover/init states
    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
2026-01-05 Fix GPIO callback conflict and use freq_counter for PPS timing
    - Fix crash caused by multiple GPIO callbacks: create shared callback
    in gps_input.c that dispatches to both GPS PPS and AC zero-crossing
    - Export ac_zero_cross_irq_handler() from ac_freq_monitor.c
    - Move GPS time setting outside state machine so it runs in any state
    - Use freq_counter (10MHz reference) for discipline offset calculation
    instead of time_us_64() - gives 100ns resolution from rubidium source
    - Fix lock threshold to use <= instead of < for 1µs comparison
    [ac_freq_monitor.c, gps_input.c, pps_capture.c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]
2026-01-05 Add atomic symbol to web interface header
    - Add ⚛ (&#9883;) Unicode atom symbol before CHRONOS-Rb title
    - Increase HTML buffer from 6KB to 12KB for safety margin
2026-01-06 Fix web page empty response and add GPS enhancements
    - Fix TCP buffer too small for status page (5840 -> 11680 bytes)
    Root cause: tcp_write() failed with ERR_MEM when page exceeded
    TCP_SND_BUF, causing empty response
    - Add GPS position with Google Maps link to web interface
    - Add GPS firmware version display (with retry mechanism)
    - Add AJAX time updates every 0.5 seconds (reduced full refresh to 30s)
    - Add OTA abort endpoint and 60-second timeout auto-abort
    - Add GPS leap seconds support from UBX-NAV-TIMELS
    - Increase lwIP MEM_SIZE from 8000 to 16000 bytes
    [chronos_rb.h, cli.c, gps_input.c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]
2026-01-07 Fix PPS offset measurement with continuous 10MHz counting
    - Fix pps_capture PIO to count continuously during PPS high period
    (was losing 100k-1M ticks/second due to different pulse widths)
    - Use Y register as state flag to capture once per rising edge
    - Add PPS offset, drift rate, and jitter statistics
    - Display FE vs GPS PPS timing on web interface
    - Use SM2/SM3 for PPS captures (SM1 appears broken on this chip)
    Results: Offset stable, drift ~3.5ppm, jitter ~13ns
    [chronos_rb.h, freq_counter.c, gps_input.c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]
2026-01-08 Add gzip-compressed OTA updates with AES encryption
    - Implement store-then-decompress OTA approach using uzlib callbacks
    - Compress firmware 457KB → 288KB (37% reduction)
    - Stream decrypt AES-ECB + decompress gzip in single pass
    - Store compressed data at 1MB offset, decompress to slot 0
    - Add PFB_WITH_GZIP_COMPRESSION and PFB_WITH_IMAGE_ENCRYPTION defines
    - Update FOTA_HOST default to 192.168.111.113
    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
2026-01-08 Add real-time log streaming, AC frequency monitor, and WiFi fixes
    - Add log buffer module for capturing printf output to web interface
    - Config page CLI now shows real-time device logs via /api/logs endpoint
    - Fix AC frequency calculation (was showing half frequency)
    - Increase AC frequency averaging to 300 samples (~5 sec window)
    - Fix AC frequency range display to use 3 decimal places
    - Fix initialization order: GPS input before AC monitor to register
    shared GPIO callback before enabling AC zero-crossing IRQ
    - Add WiFi auto-reconnection on connection loss with 30s retry
    - Rename "FE PPS" labels to "Rb PPS" throughout
    Co-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
    [ac_freq_monitor.c, chronos_rb.h, freq_counter.c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]
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2026-01-11 Rename GPS to GNSS, update baud rate to 115200, fix pulse outputs
    - Change all user-visible GPS references to GNSS
    - Update default GNSS baud rate from 9600 to 115200
    - Remove legacy hardcoded pulse generation code from main.c
    - Fix pulse CLI commands to use cli_printf for web interface output
    - Pulse outputs now fully managed by pulse_output module
    [chronos_rb.h, cli.c, main.c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]
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2026-01-11 Make GNSS primary time reference, Rb as backup
    Architecture change:
    - GNSS PPS: Primary time source (absolute accuracy)
    - Rb 10MHz: Frequency reference (stability between PPS)
    - Rb PPS: Backup/holdover when GNSS unavailable
    State machine changes:
    - INIT: Wait for GNSS lock first, fall back to Rb
    - FINE/LOCKED: Monitor GNSS PPS as primary, Rb as backup
    - HOLDOVER: Use Rb for extended holdover when GNSS lost
    - ERROR: Prioritize GNSS recovery
    Version 1.4.67
    [chronos_rb.h, rubidium_sync.c]
2026-01-11 Add PIO-based pulse generation for sub-microsecond jitter
    Pulses are now generated using PIO hardware for precise timing:
    - pulse_pio.pio: PPS-synchronized pulses (1s+ intervals)
    - pulse_interval_pio.pio: 10MHz-timed sub-second intervals
    - Up to 5 PIO-timed outputs, remaining use CPU fallback
    - Pulse list shows [PIO0 SM1] or [CPU] for each output
    [chronos_rb.h, pulse_output.c]
